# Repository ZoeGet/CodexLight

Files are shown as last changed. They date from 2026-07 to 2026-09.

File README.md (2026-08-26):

# CodexLight

[English](README.en.md) | 简体中文 | [使用说明](USAGE.md) | [English Usage Guide](USAGE.en.md)

CodexLight 是一套基于 ESP32-C3FH4 的 Codex Desktop 状态灯。Windows 端 Bridge 读取本机 Codex 会话日志，把状态转换为 `GREEN`、`RED`、`YELLOW`，再通过 USB 串口、局域网 UDP 或两者同时发送给状态灯。固件驱动三颗独立 WS2812B LED 显示空闲、工作和等待状态。

硬件采用一体化主板设计，集成 ESP32-C3FH4、2.4 GHz 天线、40 MHz 晶振、Type-C 原生 USB、电池充电与 5 V 升压以及 3.3 V 稳压电路，不需要额外安装 ESP32-C3 开发板。

本项目是社区开源项目，与 OpenAI 没有官方关联或背书。

## 当前可用方案

- 配网使用 USB 串口，不再使用 ESP32 AP 热点页面。
- 托盘程序提供 `Configure WiFi`，通过 USB 把 SSID 和密码发送给设备。
- Wi-Fi 只在连接成功后写入 ESP32 NVS；错误密码不会覆盖旧配置。
- 已保存的 Wi-Fi 会在开机后非阻塞连接，并在断线后持续重试。
- ESP32-C3 使用 SDK 默认的 Wi-Fi 发射功率，由 PHY 和地区配置决定。
- 无电脑供电启动不依赖 USB 串口，可使用板载电池接口或稳定 5 V 电源进行纯无线摆放。
- 支持 `AUTO`、`WIRED`、`WIRELESS` 三种持久化通信模式。
- 普通用户直接双击单文件 `Bridge/CodexLightTray.exe`；程序内置 Python 运行时并默认以无线模式驻留系统托盘。

## 状态定义

| 状态 | Codex 条件 | LED | GPIO |
| --- | --- | --- | --- |
| `GREEN` | 空闲、任务完成或任务中止 | 绿灯 | GPIO6 |
| `RED` | 正在思考、回复、运行工具或处理任务 | 红灯 | GPIO7 |
| `YELLOW` | 等待审批、权限确认或用户输入 | 黄灯 | GPIO5 |
| 未收到电脑心跳 | 6 秒内没有有效 USB/UDP 心跳 | 黄灯慢闪 | GPIO5 |

Bridge 兼容 Codex 会话日志中的普通工具调用和自定义工具调用事件，因此系统权限审批、沙箱授权和显式用户输入等待都能进入黄色状态。

首次收到有效电脑心跳时，绿灯会闪烁 2 秒作为连接提示，然后显示真实状态。任务完成后的绿色会保持到下一次任务开始、进入等待状态或连接断开。

## 快速开始

1. 编译并烧录固件：

   ```powershell
   cd Firmware
   pio run
   pio run -t upload --upload-port COM4
   ```

2. 双击启动托盘 EXE，默认进入无线模式，无需另行安装 Python：

   ```text
   Bridge\CodexLightTray.exe
   ```

3. 第一次使用时，用可传输数据的 Type-C 线连接设备，右键托盘图标选择 `Configure WiFi`，输入路由器 SSID 和密码。
4. Wi-Fi 保存成功后，可以拔掉电脑 USB，改用稳定 5 V 电源或从 MX1.25 接口接入的受保护单节锂电池供电；托盘会通过 UDP 控灯。

首次运行 EXE 会把内置运行环境和日志释放到 `%LOCALAPPDATA%\CodexLight`。Windows 防火墙首次询问时，请允许专用网络访问。

完整流程见 [USAGE.md](USAGE.md)。

## 纯无线使用

1. 先用 USB 完成一次 `Configure WiFi`。
2. 确认托盘模式是 `Wireless only`，或直接启动默认无线模式的 `CodexLightTray.exe`。
3. 断开电脑 USB，使用稳定 5 V 电源或从 MX1.25 接口接入的受保护单节锂电池给整机供电。
4. 打开托盘后，日志应出现：

   ```text
   SERIAL no matching serial port
   SERIAL setup skipped; using saved firmware mode.
   UDP ack from 192.168.x.x CODEXLIGHT/1 ACK ... active=WIRELESS state=...
   ```

这表示设备未接电脑串口，但已通过 Wi-Fi UDP 正常工作。

## 无串口诊断灯码

| 灯码 | 含义 |
| --- | --- |
| 红黄交替 | 没有读到 Wi-Fi 配置，需要 USB 配网 |
| 红色双闪循环 | 有 Wi-Fi 配置，但正在重连或连接失败 |
| 黄灯慢闪 | Wi-Fi 已连接，正在等待电脑托盘 UDP 心跳 |
| 正常红/绿/黄 | 已收到电脑状态，系统正常工作 |

## 硬件

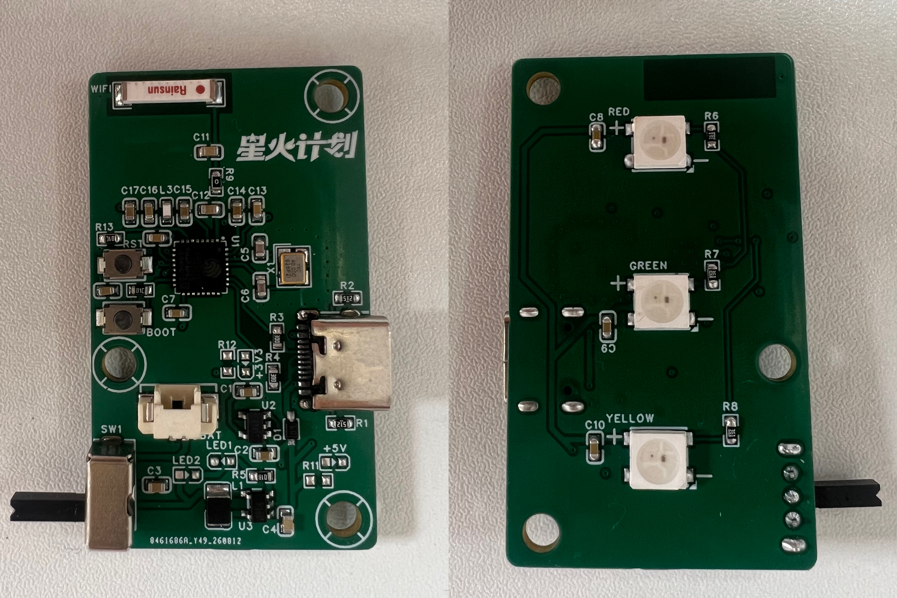
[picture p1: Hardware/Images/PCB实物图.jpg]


上图为当前一体化主板的正反面焊接实物，可见 ESP32-C3FH4、Type-C、电池接口与开关、天线、ETA6093S2F 电源区域以及三颗独立 WS2812B 状态灯。

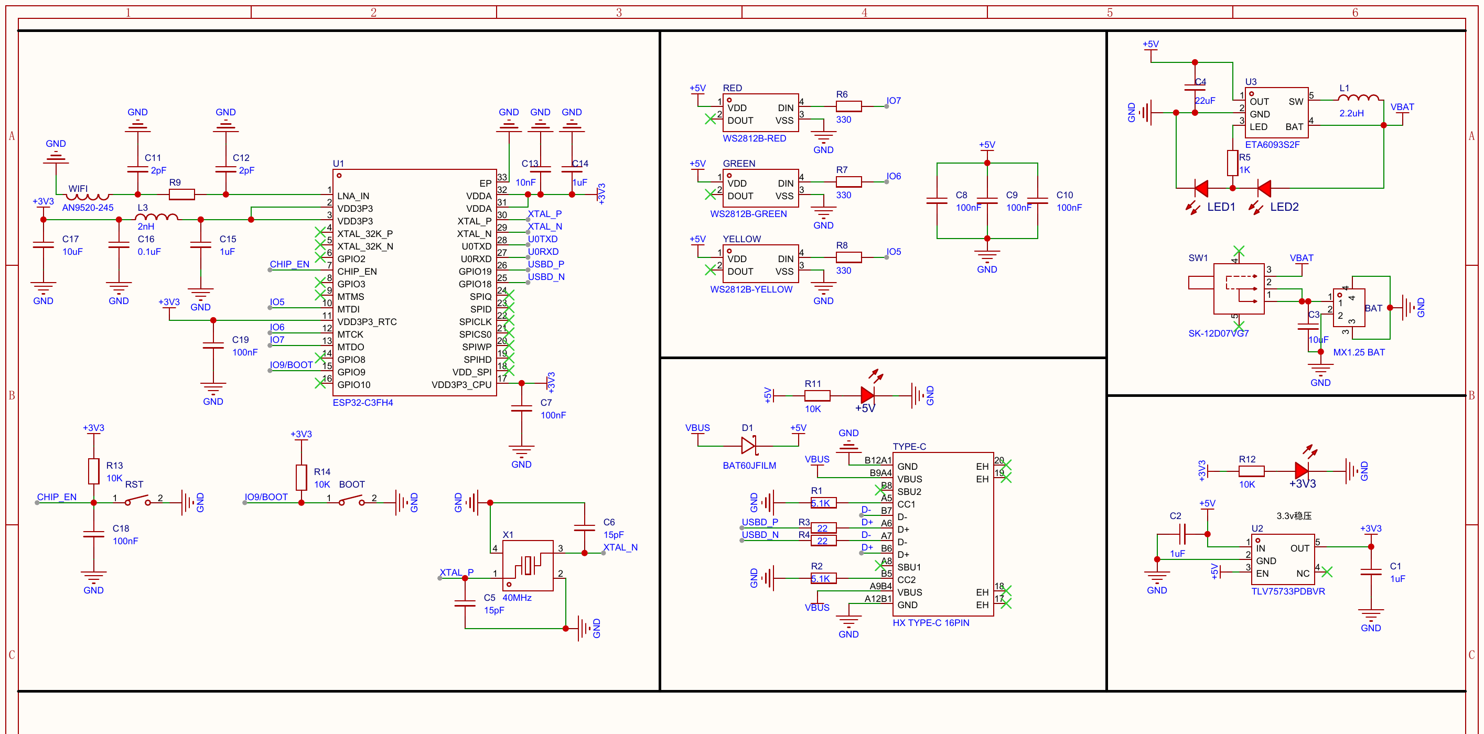
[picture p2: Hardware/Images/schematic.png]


当前硬件是围绕 ESP32-C3FH4 设计的一体化主板，完整原理图见 [Hardware/Schematic/Schematic.pdf](Hardware/Schematic/Schematic.pdf)。

| 功能模块 | 主要器件与连接 |
| --- | --- |
| 主控与时钟 | ESP32-C3FH4，外接 40 MHz 晶振；RST 接 CHIP_EN，BOOT 接 GPIO9 |
| 无线射频 | AN9520-245 2.4 GHz 天线，R9/C11/C12 预留射频匹配网络 |
| USB Type-C | 原生 USB D+/D- 分别连接 GPIO19/GPIO18，并串联 22 Ω；CC1、CC2 各使用 5.1 kΩ 下拉 |
| USB 供电 | VBUS 经 BAT60JFILM 肖特基二极管接入系统 +5 V |
| 电池供电 | ETA6093S2F 负责单节锂电池开关充电和 5 V 同步升压，使用 2.2 µH 电感、22 µF 输出电容、MX1.25 电池接口和电源开关 |
| 3.3 V 电源 | TLV75733PDBVR 将 +5 V 稳压为 +3.3 V，为 ESP32-C3FH4 和逻辑电路供电 |
| 状态灯 | 黄灯 GPIO5、绿灯 GPIO6、红灯 GPIO7；每路串联 330 Ω，并配置 100 nF 去耦电容 |

<p>
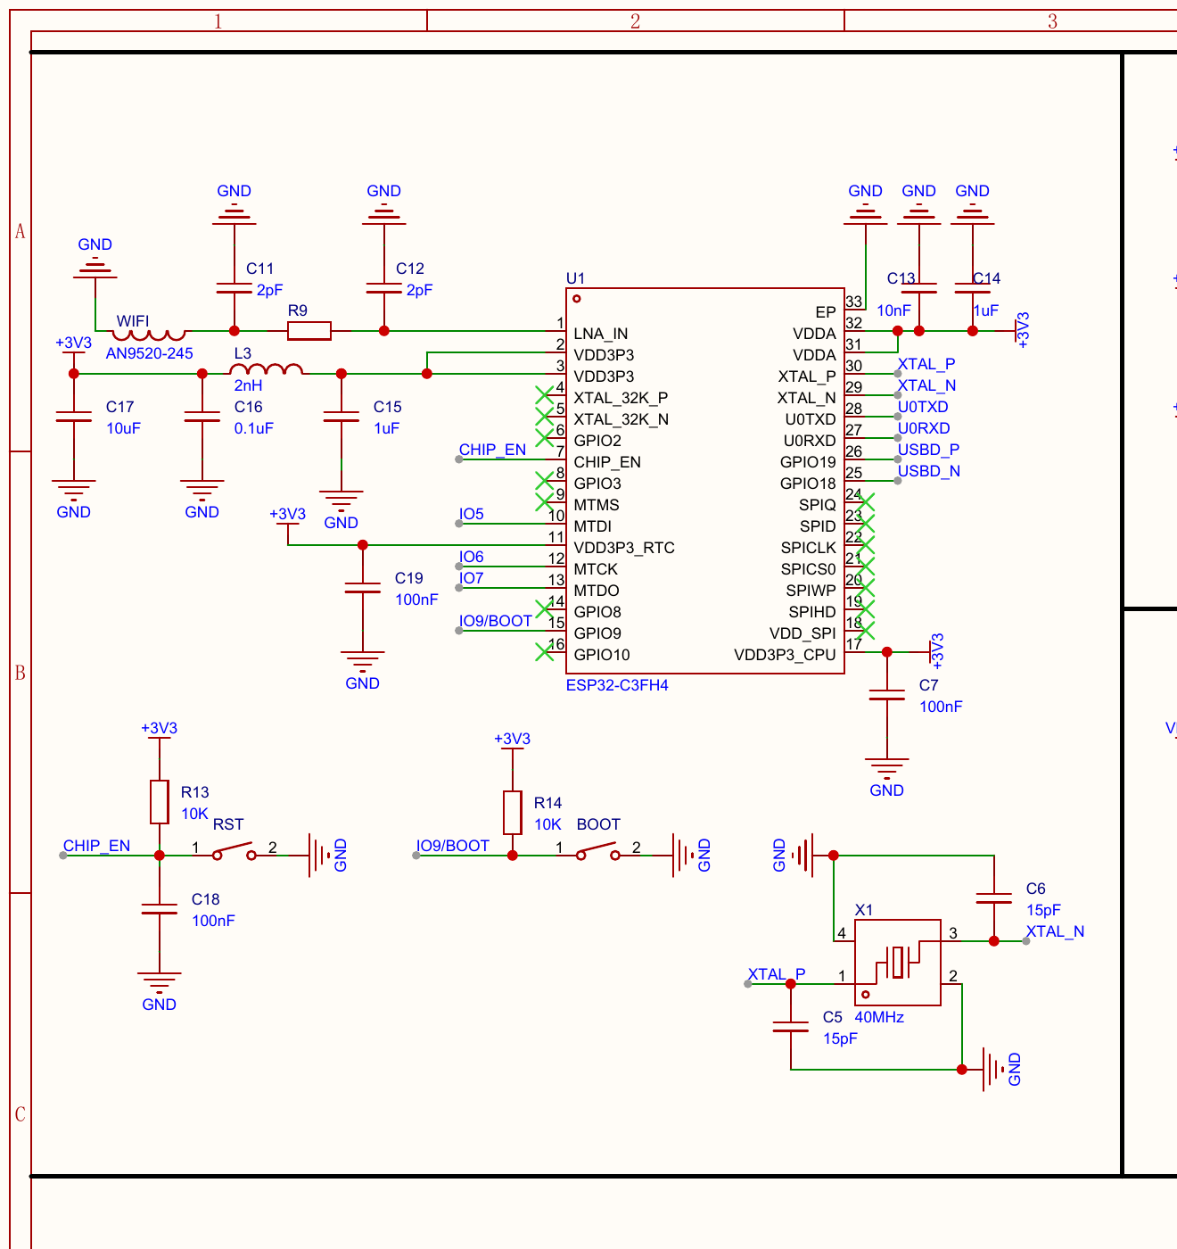
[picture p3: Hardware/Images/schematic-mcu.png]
  
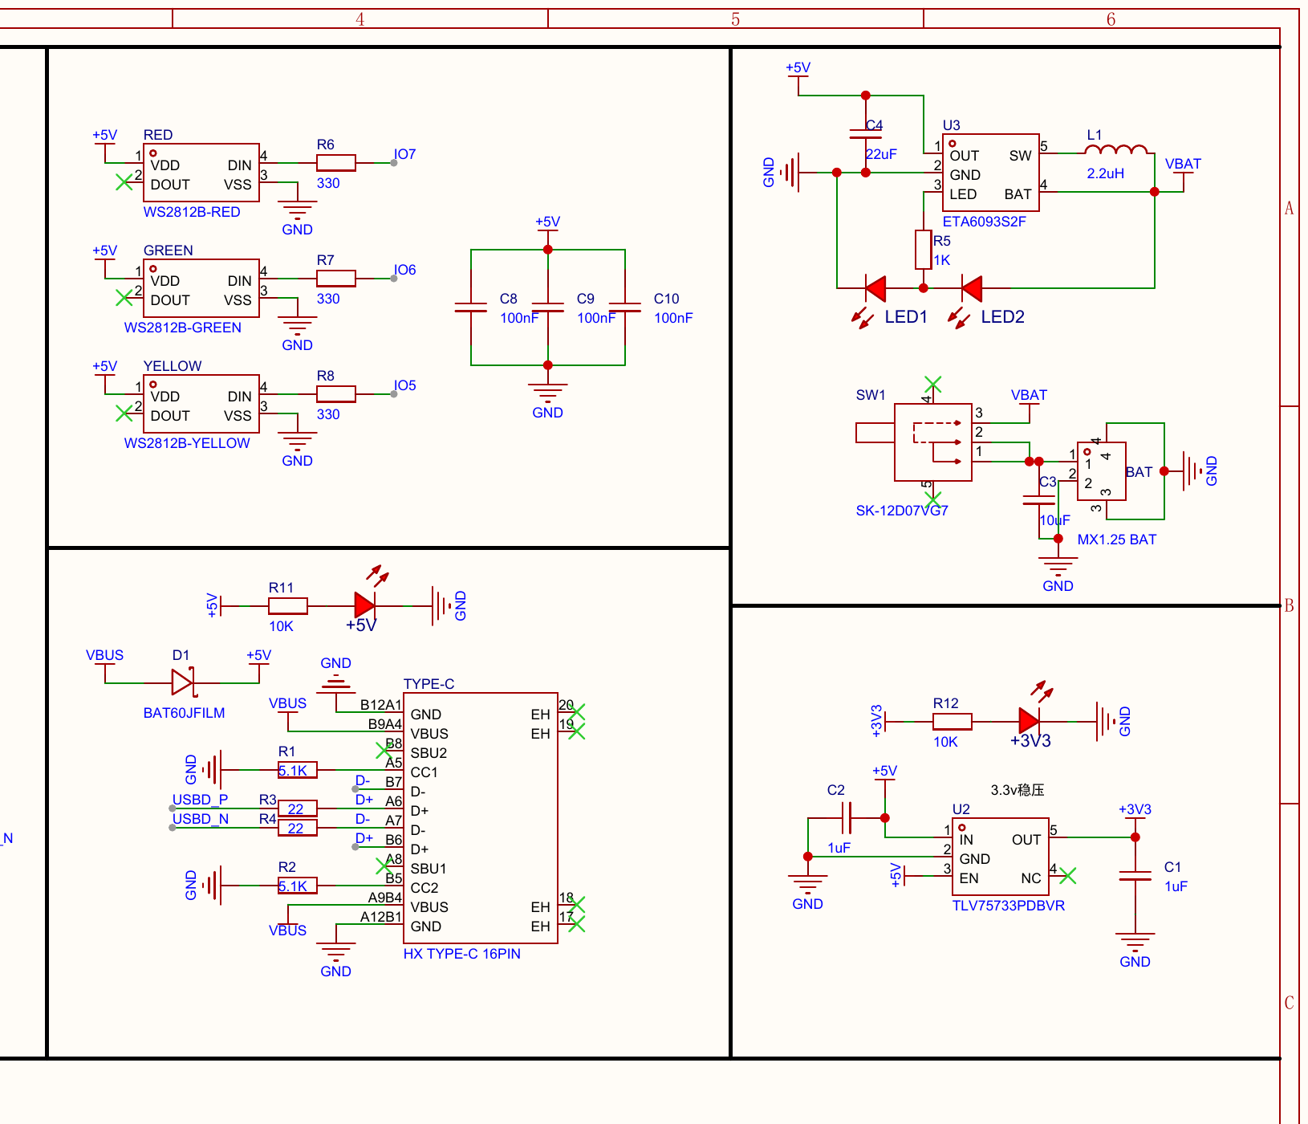
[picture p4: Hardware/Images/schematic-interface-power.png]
  
</p>

左图为 ESP32-C3FH4 主控、射频、晶振及 RST/BOOT 电路，右图为三路状态灯、Type-C、电池管理和 3.3 V 稳压电路。

三颗 WS2812B 使用三路独立数据输入，不是串联灯带。灯珠使用 +5 V 供电，ESP32-C3FH4 使用 +3.3 V 供电，二者必须共地。当前固件使用 `NEO_GRB + NEO_KHZ800`，默认亮度为 `DEFAULT_BRIGHTNESS = 50`，可在 [Firmware/include/config.h](Firmware/include/config.h) 中配置。

ETA6093S2F 的 `LED` 引脚通过 R5（1 kΩ）连接 LED1、LED2，用于显示充电和升压工作状态；L1（2.2 µH）连接 `SW` 与 `VBAT`，C4（22 µF）用于 +5 V 输出滤波，C3（10 µF）用于电池侧去耦。电池必须核对接口极性并带有保护电路。更详细的电路说明和组装注意事项见 [开源平台项目说明](Docs/立创开源平台项目说明.md)。

## 目录结构

```text
CodexLight/
├── Bridge/        # Windows 日志监听、串口/UDP 发送和托盘程序
├── Firmware/      # ESP32-C3 PlatformIO 固件
├── Hardware/      # BOM、原理图、PCB、Gerber、贴片坐标、外壳 STL
├── Docs/          # 使用与实现说明
├── README.md      # 中文项目说明
├── README.en.md   # English project documentation
├── USAGE.md       # 中文使用手册
└── USAGE.en.md    # English usage guide
```

## 验证

```powershell
python -B -m py_compile Bridge\Source\codex_light_monitor.py
powershell -NoProfile -Command "$e=$null; [System.Management.Automation.PSParser]::Tokenize((Get-Content -LiteralPath 'Bridge\Source\CodexLightTray.ps1' -Raw), [ref]$e) | Out-Null; if($e){$e; exit 1}else{'OK'}"
cd Firmware
pio run
```

## 许可

本项目使用 [MIT License](LICENSE)。第三方依赖遵循各自许可。

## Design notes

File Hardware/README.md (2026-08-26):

# CodexLight Hardware

[项目主页](../README.md) | [Project Home](../README.en.md)

本目录包含 CodexLight 的 BOM、原理图、PCB 源工程、Gerber、贴片坐标文件和 3D 打印外壳。

This directory contains the CodexLight bill of materials, schematic, PCB source project, Gerber files, component placement list, and 3D-printable enclosure.

## Files / 文件

| Path | Description |
| --- | --- |
| `BOM/BOM.xls` | 物料清单 / Bill of materials |
| `Schematic/Schematic.pdf` | 原理图 PDF / Schematic PDF |
| `PCB/Source/CodexLight.epro2` | PCB 源工程 / PCB source project |
| `PCB/Gerber/CodexLight_PCB_Gerber.zip` | Gerber 制造包 / Gerber fabrication package |
| `PCB/Assembly/CodexLight_PCB_CPL.csv` | 元件贴片坐标文件 / Component placement list |
| `Enclosure/CodexLight_T.stl` | 上壳 / Top enclosure |
| `Enclosure/CodexLight_B.stl` | 下壳 / Bottom enclosure |

## LED Connections / LED 连接

| LED | GPIO |
| --- | --- |
| Yellow WS2812B DIN / 黄灯 DIN | GPIO5 |
| Green WS2812B DIN / 绿灯 DIN | GPIO6 |
| Red WS2812B DIN / 红灯 DIN | GPIO7 |

三颗 LED 使用独立数据线，不是串联灯带。LED 电源和 ESP32-C3 必须共地，并使用稳定 5 V 供电。

The three LEDs use independent data lines, not a chained strip. The LED supply and ESP32-C3 must share ground, and a stable 5 V supply is required.

## Assembly Photo / 焊接实物



图片展示当前一体化主板正反面的焊接结果，包括主控、射频、USB、电池管理、稳压和三颗状态灯区域。

The image shows the assembled front and back sides of the current all-in-one board, including the MCU, RF, USB, battery-management, regulator, and status-LED sections.

## Standalone Power / 独立供电

纯无线使用时，可以通过 Type-C/稳定 5 V 电源供电，也可以从 MX1.25 接口接入带保护的单节锂电池。ETA6093S2F 负责单节锂电池开关充电和 5 V 同步升压，TLV75733PDBVR 再生成 ESP32-C3FH4 使用的 3.3 V。接入电池前必须核对接口极性。

For wireless-only use, power the device through USB Type-C or a stable 5 V supply, or connect a protected single-cell Li-ion battery through MX1.25. The ETA6093S2F handles switch-mode charging and synchronous 5 V boost power, while the TLV75733PDBVR generates 3.3 V for the ESP32-C3FH4. Verify battery connector polarity before connection.

## Notes / 注意

- 固件默认使用 `NEO_GRB + NEO_KHZ800`。
- 如果更换不同批次 WS2812B 后颜色不对，请检查色序、DIN 方向、焊接和供电。
- 固件烧录和首次 Wi-Fi 配网需要可传输数据的 Type-C 线。
- ETA6093S2F 的 `LED` 引脚通过 R5（1 kΩ）驱动 LED1、LED2；L1 为 2.2 µH，+5 V 输出端 C4 为 22 µF，电池侧 C3 为 10 µF。电池应带保护电路并核对接口极性。
- 当前 `BOM.xls` 和 `CodexLight_PCB_CPL.csv` 仍包含旧的 ETA9697E8A 记录，正式生产前需要从新版 EasyEDA 工程重新导出并核对封装、坐标和旋转方向。
- `CodexLight_PCB_CPL.csv` 包含顶层和底层元件坐标；提交贴片订单前应在生产平台预览并核对元件层、坐标和旋转方向。

- Firmware defaults to `NEO_GRB + NEO_KHZ800`.
- If another WS2812B batch displays incorrect colors, verify pixel order, DIN orientation, soldering, and power.
- Firmware upload and first-time Wi-Fi provisioning require a data-capable USB Type-C cable.
- The ETA6093S2F `LED` pin drives LED1 and LED2 through R5 (1 kΩ). L1 is 2.2 µH, C4 is 22 µF on the +5 V output, and C3 is 10 µF on the battery side. Use a protected battery and verify connector polarity.
- The current `BOM.xls` and `CodexLight_PCB_CPL.csv` still contain the previous ETA9697E8A entry. Re-export them from the updated EasyEDA project and verify the footprint, coordinates, and rotation before production.
- `CodexLight_PCB_CPL.csv` contains top- and bottom-side component coordinates. Preview the assembly order and verify layer, position, and rotation data before production.

## License

Unless a third-party component states otherwise, hardware files follow the repository [MIT License](../LICENSE).

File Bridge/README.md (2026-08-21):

# CodexLight Bridge

[English](README_en.md) | 简体中文 | [项目主页](../README.md)

Bridge 运行在 Windows 电脑上，读取本机 Codex Desktop 会话日志，把状态映射为 `GREEN`、`RED`、`YELLOW`，再通过 USB 串口、局域网 UDP 或两者同时发送给 ESP32-C3。

## 功能

- 监听 `~/.codex/sessions/**/*.jsonl` 和 `~/.codex/logs_2.sqlite`。
- 支持 USB 串口、UDP、AUTO 混合模式。
- 提供 Windows 托盘菜单：配网、切换模式、查看日志、重启监控、退出。
- 通过 USB 串口为设备配置 Wi-Fi，不使用 ESP32 AP 热点。
- 自动记住最近发现的 UDP 设备，方便下次启动继续使用无线连接。
- 无电脑 USB 时，托盘会跳过串口设置并继续用已保存的无线模式发送 UDP。

## 状态规则

| Codex 事件 | 输出 |
| --- | --- |
| `task_started`、推理、消息、工具调用和工具输出 | `RED` |
| 工具调用需要审批、权限或用户输入 | `YELLOW` |
| `task_complete` 或 `turn_aborted` | `GREEN` |

Bridge 同时兼容 `function_call` / `function_call_output` 和 `custom_tool_call` / `custom_tool_call_output`。当工具调用包含 `require_escalated`、`sandbox_permissions`、`request_user_input` 或其他审批/权限标记时，状态保持为 `YELLOW`，直到对应的工具输出到达。

Bridge 只发送颜色状态，不发送 Codex 消息正文、工具输出、API Key 或登录令牌。

## 依赖

直接使用已构建的 `CodexLightTray.exe` 不需要另行安装 Python。只有从源码启动或重新构建 EXE 时需要本机 Python；源码启动还需要：

```powershell
python -m pip install pyserial
```

## 托盘启动

普通用户直接双击单文件程序：

```text
Bridge\CodexLightTray.exe
```

EXE 内置 64 位 Python 运行时和串口库，首次启动会释放到 `%LOCALAPPDATA%\CodexLight`，日志和本地设备配置也保存在该目录。首次使用 UDP 时，Windows 防火墙可能询问是否允许网络访问，请允许专用网络。

从源码启动时，推荐双击隐藏启动器，默认进入 `WIRELESS` 模式：

```text
Bridge\Source\start_codex_light_tray.vbs
```

旧批处理也可用，但可能短暂显示控制台窗口：

```text
Bridge\Source\start_codex_light_tray.bat
```

托盘菜单：

- `Configure WiFi`：通过 USB 写入路由器 SSID/密码。
- `Connection mode`：切换 `Auto (wired + wireless)`、`Wired only`、`Wireless only`。
- `Open log folder`：打开当前运行版本的日志目录；EXE 版为 `%LOCALAPPDATA%\CodexLight\logs`，源码版为 `Bridge\Source\logs`。
- `Restart monitor`：重启监控进程。
- `Exit`：退出。

重新构建单文件 EXE：

```powershell
powershell -ExecutionPolicy Bypass -File Bridge\Source\build_tray_exe.ps1
```

输出文件为 `Bridge\CodexLightTray.exe`。构建过程使用本机 64 位 Python 和 Windows 自带的 .NET Framework C# 编译器，不需要联网。

## Wi-Fi 配网

托盘 `Configure WiFi` 会暂停监控进程，打开串口，发送：

```text
WIFI_SET <ssid><TAB><password>
```

设备连接成功后返回：

```text
WIFI_SET_OK <ssid> <ip>
```

EXE 版失败日志保存到：

```text
%LOCALAPPDATA%\CodexLight\logs\wifi_setup.out.log
%LOCALAPPDATA%\CodexLight\logs\wifi_setup.err.log
```

源码版失败日志保存到 `Bridge\Source\logs`。

命令行配网：

```powershell
python Bridge\Source\codex_light_monitor.py --serial auto --wifi-ssid "YourWifi" --wifi-password "YourPassword"
```

## 运行模式

| 模式 | Bridge 行为 |
| --- | --- |
| `WIRED` | 打开串口并只通过 USB 发送状态 |
| `WIRELESS` | 通过 UDP 发送状态；如果 USB 存在，会用串口保存 `MODE WIRELESS` 后释放；如果 USB 不存在，会直接使用设备已保存模式 |
| `AUTO` | 串口和 UDP 同时启用，固件优先使用新鲜串口心跳 |

手动运行：

```powershell
python Bridge\Source\codex_light_monitor.py --serial auto --baud 115200
python Bridge\Source\codex_light_monitor.py --udp --udp-port 4210
python Bridge\Source\codex_light_monitor.py --serial auto --baud 115200 --udp --udp-port 4210 --firmware-mode AUTO
```

## 常用参数

| 参数 | 说明 |
| --- | --- |
| `--serial COM4` | 指定串口 |
| `--serial auto` | 自动选择常见 ESP32/USB 串口 |
| `--baud 115200` | 串口波特率 |
| `--udp` | 启用 UDP 状态发送和发现 |
| `--udp-port 4210` | UDP 端口 |
| `--firmware-mode AUTO` | 通过串口保存固件模式 |
| `--serial-setup-only` | 串口只用于模式设置，确认后释放 |
| `--reset-on-connect` | 打开串口后发送 ESP32 reset pulse，用于无线托盘启动时初始化设备 |
| `--wifi-ssid` / `--wifi-password` | 一次性 USB Wi-Fi 配网 |
| `--wifi-config path.json` | 从 JSON 文件读取 `{ "ssid": "...", "password": "..." }` |

## 日志

- EXE 版：`%LOCALAPPDATA%\CodexLight\logs`
- 源码版：`Bridge\Source\logs`
- 两种版本均包含 `codex_light_monitor.out.log`、`codex_light_monitor.err.log`、`wifi_setup.out.log`、`wifi_setup.err.log`。

## 验证

```powershell
python -B -m py_compile Bridge\Source\codex_light_monitor.py
powershell -NoProfile -Command "$e=$null; [System.Management.Automation.PSParser]::Tokenize((Get-Content -LiteralPath 'Bridge\Source\CodexLightTray.ps1' -Raw), [ref]$e) | Out-Null; if($e){$e; exit 1}else{'OK'}"
```

## License

Bridge 遵循仓库根目录的 [MIT License](../LICENSE)。

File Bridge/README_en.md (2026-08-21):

# CodexLight Bridge

English | [简体中文](README.md) | [Project Home](../README.en.md)

The Bridge runs on the Windows computer hosting Codex Desktop. It reads local Codex session logs, maps activity to `GREEN`, `RED`, or `YELLOW`, and sends the state to the ESP32-C3 over USB serial, LAN UDP, or both.

## Features

- Monitors `~/.codex/sessions/**/*.jsonl` and `~/.codex/logs_2.sqlite`.
- Supports USB serial, UDP, and mixed AUTO mode.
- Provides a Windows tray menu for Wi-Fi setup, mode switching, logs, monitor restart, and exit.
- Configures device Wi-Fi over USB serial. The firmware no longer uses an ESP32 AP portal.
- Remembers the most recently discovered UDP device for wireless startup.
- When no computer USB is connected, the tray skips serial setup and continues UDP using the device's saved wireless mode.

## State Rules

| Codex event | Output |
| --- | --- |
| `task_started`, reasoning, messages, tool calls, and tool outputs | `RED` |
| A tool call requires approval, permission, or user input | `YELLOW` |
| `task_complete` or `turn_aborted` | `GREEN` |

The Bridge supports both `function_call` / `function_call_output` and `custom_tool_call` / `custom_tool_call_output`. When a tool call contains `require_escalated`, `sandbox_permissions`, `request_user_input`, or another approval/permission marker, the state remains `YELLOW` until the matching tool output arrives.

The Bridge sends only color states. It never sends Codex message text, tool output, API keys, or login tokens to the device.

## Dependency

The built `CodexLightTray.exe` does not require a separate Python installation. Local Python is needed only when running from source or rebuilding the EXE; source mode also requires:

```powershell
python -m pip install pyserial
```

## Tray Startup

For normal use, double-click the standalone executable:

```text
Bridge\CodexLightTray.exe
```

The EXE embeds a 64-bit Python runtime and pyserial. On first launch it extracts runtime files to `%LOCALAPPDATA%\CodexLight`; logs and local device configuration are stored there as well. Windows Firewall may ask for network access the first time UDP is used; allow private networks.

When running from source, use the hidden launcher. It defaults to `WIRELESS` mode:

```text
Bridge\Source\start_codex_light_tray.vbs
```

The legacy batch launcher is also available, but it may briefly show a console window:

```text
Bridge\Source\start_codex_light_tray.bat
```

Tray menu:

- `Configure WiFi`: write router SSID/password over USB.
- `Connection mode`: switch between `Auto (wired + wireless)`, `Wired only`, and `Wireless only`.
- `Open log folder`: open the active runtime log directory; `%LOCALAPPDATA%\CodexLight\logs` for the EXE and `Bridge\Source\logs` for source mode.
- `Restart monitor`: restart the monitor process.
- `Exit`: quit.

Rebuild the standalone EXE with:

```powershell
powershell -ExecutionPolicy Bypass -File Bridge\Source\build_tray_exe.ps1
```

The output is `Bridge\CodexLightTray.exe`. The build uses local 64-bit Python and the Windows .NET Framework C# compiler, and does not require network access.

## Wi-Fi Provisioning

The tray `Configure WiFi` action pauses the monitor process, opens serial, and sends:

```text
WIFI_SET <ssid><TAB><password>
```

On success, the device replies:

```text
WIFI_SET_OK <ssid> <ip>
```

EXE failure logs are written to:

```text
%LOCALAPPDATA%\CodexLight\logs\wifi_setup.out.log
%LOCALAPPDATA%\CodexLight\logs\wifi_setup.err.log
```

Source-mode failure logs are written under `Bridge\Source\logs`.

Command-line provisioning:

```powershell
python Bridge\Source\codex_light_monitor.py --serial auto --wifi-ssid "YourWifi" --wifi-password "YourPassword"
```

## Run Modes

| Mode | Bridge behavior |
| --- | --- |
| `WIRED` | Opens serial and sends states only over USB |
| `WIRELESS` | Sends states over UDP; if USB exists, serial saves `MODE WIRELESS` and is released; if USB is absent, the saved firmware mode is used |
| `AUTO` | Enables serial and UDP; firmware prefers a fresh serial heartbeat |

Manual commands:

```powershell
python Bridge\Source\codex_light_monitor.py --serial auto --baud 115200
python Bridge\Source\codex_light_monitor.py --udp --udp-port 4210
python Bridge\Source\codex_light_monitor.py --serial auto --baud 115200 --udp --udp-port 4210 --firmware-mode AUTO
```

## Common Options

| Option | Description |
| --- | --- |
| `--serial COM4` | Use a specific serial port |
| `--serial auto` | Auto-select a common ESP32/USB serial device |
| `--baud 115200` | Serial baud rate |
| `--udp` | Enable UDP state output and discovery |
| `--udp-port 4210` | UDP port |
| `--firmware-mode AUTO` | Persist firmware mode over serial |
| `--serial-setup-only` | Use serial only for mode setup, then release it |
| `--reset-on-connect` | Pulse ESP32 reset lines after opening serial; used by wireless tray startup to initialize the device |
| `--wifi-ssid` / `--wifi-password` | One-shot USB Wi-Fi provisioning |
| `--wifi-config path.json` | Read `{ "ssid": "...", "password": "..." }` from JSON |

## Logs

- EXE build: `%LOCALAPPDATA%\CodexLight\logs`
- Source mode: `Bridge\Source\logs`
- Both contain `codex_light_monitor.out.log`, `codex_light_monitor.err.log`, `wifi_setup.out.log`, and `wifi_setup.err.log`.

## Verification

```powershell
python -B -m py_compile Bridge\Source\codex_light_monitor.py
powershell -NoProfile -Command "$e=$null; [System.Management.Automation.PSParser]::Tokenize((Get-Content -LiteralPath 'Bridge\Source\CodexLightTray.ps1' -Raw), [ref]$e) | Out-Null; if($e){$e; exit 1}else{'OK'}"
```

## License

The Bridge is covered by the repository's [MIT License](../LICENSE).

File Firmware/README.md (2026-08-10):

# CodexLight Firmware

[项目主页](../README.md) | [Project Home](../README.en.md)

本目录是 ESP32-C3 端 PlatformIO Arduino 固件。固件负责 USB Wi-Fi 配网、STA 联网、USB 串口/UDP 心跳接收、通信模式持久化、无串口启动诊断灯码和三路 WS2812B 状态显示。

This directory contains the ESP32-C3 PlatformIO Arduino firmware. It handles USB Wi-Fi provisioning, STA networking, USB serial/UDP heartbeats, persistent transport modes, standalone LED diagnostics, and three independent WS2812B status LEDs.

## Build Environment / 构建环境

```ini
platform = espressif32@6.6.0
board = esp32-c3-devkitm-1
framework = arduino
monitor_speed = 115200
```

PlatformIO installs the external dependency automatically:

- `Adafruit NeoPixel`

当前固件不再依赖 `WiFiManager`、`ESPAsyncWebServer` 或 AP 配网页面。

The current firmware no longer depends on `WiFiManager`, `ESPAsyncWebServer`, or an AP provisioning portal.

## Build and Upload / 编译与烧录

```powershell
cd Firmware
pio run
pio run -t upload --upload-port COM4
pio device monitor --port COM4 --baud 115200
```

普通串口监视器会占用 COM 口。使用 Bridge 或托盘前请关闭 PlatformIO Monitor。

Close PlatformIO Monitor before starting the Bridge or tray because only one process can use the COM port.

## Main Configuration / 主要配置

Edit `include/config.h`:

| Setting | Default | Description |
| --- | --- | --- |
| `YELLOW_LED_PIN` | `5` | Yellow LED data pin |
| `GREEN_LED_PIN` | `6` | Green LED data pin |
| `RED_LED_PIN` | `7` | Red LED data pin |
| `DEFAULT_BRIGHTNESS` | `50` | NeoPixel brightness |
| `SERIAL_BAUD` | `115200` | USB CDC baud rate |
| `UDP_PORT` | `4210` | UDP listen/discovery port |
| `LINK_TIMEOUT_MS` | `6000` | Desktop heartbeat timeout |
| `WIFI_CONNECT_TIMEOUT_MS` | `15000` | Blocking connect timeout used only during USB provisioning validation |
| `WIFI_RECONNECT_INTERVAL_MS` | `10000` | Non-blocking saved Wi-Fi retry interval |
| `DEFAULT_TRANSPORT_MODE` | `AUTO` | Default mode when NVS has none |
| `DEBUG_SERIAL` | `false` | Default debug logging; keep disabled for standalone wireless operation |

`CONFIG_AP_*` constants are retained only for compatibility. The main firmware does not start a SoftAP.

`CONFIG_AP_*` 常量仅保留兼容用途，主固件不会启动热点。

## Wi-Fi Provisioning / Wi-Fi 配网

Use USB serial:

```text
WIFI_SET <ssid><TAB><password>
```

During provisioning, the firmware validates the credentials by attempting STA connection. Credentials are saved in Preferences namespace `wifi` only after successful connection:

```text
ssid
password
```

配网失败不会覆盖旧配置。保存过 Wi-Fi 后，启动时使用非阻塞连接；如果连接失败，固件保留凭据并按 `WIFI_RECONNECT_INTERVAL_MS` 持续重试。

Failed provisioning does not overwrite existing credentials. Once Wi-Fi is saved, boot uses a non-blocking connect path. If the connection fails, credentials are kept and the firmware retries every `WIFI_RECONNECT_INTERVAL_MS`.

Clear Wi-Fi:

```text
CLEAR_WIFI
```

## Transport Modes / 通信模式

| Mode | Behavior |
| --- | --- |
| `WIRED` | Accept USB serial heartbeat only |
| `WIRELESS` | Accept UDP heartbeat only |
| `AUTO` | Accept both; fresh USB heartbeat has priority |

Commands:

```text
MODE WIRED
MODE WIRELESS
MODE AUTO
STATUS
```

The selected mode is saved in Preferences namespace `codexlight`, key `transport`.

## LED Runtime and Diagnostics / LED 运行与诊断

| Pattern | Meaning |
| --- | --- |
| Solid green | Idle, task complete, or task aborted |
| Solid red | Codex is working |
| Solid yellow | Waiting for approval, permission, or user input |
| Green blink for 2 seconds | First desktop heartbeat connected |
| Slow yellow blink | Wi-Fi is connected but no desktop heartbeat has arrived |
| Alternating red/yellow | No saved Wi-Fi credentials |
| Repeating red double-blink | Saved Wi-Fi exists but reconnect is in progress or failed |

独立供电时不要依赖串口输出判断状态，直接看灯码即可。

When running from a power bank or battery, use the LED diagnostics instead of serial output.

## Serial Commands / 串口命令

```text
GREEN
RED
YELLOW
PING
STATUS
MODE WIRED
MODE WIRELESS
MODE AUTO
WIFI_CONFIG
WIFI_SET <ssid><TAB><password>
CLEAR_WIFI
LED_TEST RED
LED_TEST GREEN
LED_TEST YELLOW
LED_TEST OFF
```

`WIFI_CONFIG` only prints the USB provisioning hint. It does not open an AP.

`WIFI_CONFIG` 只提示使用 USB 配网，不会打开热点。

## UDP Protocol / UDP 协议

Accepted packets:

```text
CODEXLIGHT/1 GREEN
CODEXLIGHT/1 RED
CODEXLIGHT/1 YELLOW
CODEXLIGHT/1 PING
```

Acknowledgement:

```text
CODEXLIGHT/1 ACK mac=<MAC> mode=<MODE> active=<TRANSPORT> state=<STATE>
```

Discovery:

```text
CODEXLIGHT/1 HELLO mac=<MAC> mode=<MODE>
```

## Files / 文件

- `src/main.cpp`: serial commands, UDP heartbeat, transport selection, LED state machine, diagnostics.
- `src/config_portal.cpp`: STA Wi-Fi, USB provisioning wrapper, non-blocking saved Wi-Fi reconnect.
- `src/storage.cpp`: Preferences read/write for Wi-Fi credentials.
- `src/led.cpp`: three independent Adafruit NeoPixel outputs.
- `include/config.h`: user-editable GPIO, timing, brightness, port, and Wi-Fi power settings.
- `platformio.ini`: PlatformIO environment and dependencies.

## NVS and Reset / NVS 与擦除

Wi-Fi credentials and transport mode are stored in NVS. Normal firmware upload does not erase them.

```powershell
pio run -t erase --upload-port COM4
pio run -t upload --upload-port COM4
```

Usually `CLEAR_WIFI` and `MODE ...` are enough. Full erase is only needed for factory reset or corrupted NVS.

## License

Firmware follows the repository [MIT License](../LICENSE). Third-party dependencies keep their own licenses.

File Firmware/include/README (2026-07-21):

# Firmware Headers

Project header files / 项目头文件：

- `config.h`: GPIO assignments, brightness, serial baud, UDP port, timeouts, default transport mode, and LED colors. AP constants are retained for compatibility but the main firmware does not start an AP.
- `config_portal.h`: STA Wi-Fi connection and USB provisioning wrapper. The name is kept for compatibility with older code.
- `storage.h`: Preferences storage for Wi-Fi SSID/password.
- `led.h`: three-channel LED controller interface.

用户通常只需要修改 `config.h`。修改后重新运行 `pio run` 并烧录。

Users normally edit `config.h` only. Rebuild and upload after changing it.

See `Firmware/README.md` and the repository root README for complete instructions.

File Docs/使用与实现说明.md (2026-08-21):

# CodexLight 使用与实现说明

[English](USAGE_AND_IMPLEMENTATION.md) | 简体中文 | [返回文档索引](README.md) | [项目主页](../README.md)

本文合并项目操作手册和技术实现说明，覆盖固件烧录、USB Wi-Fi 配网、有线/无线运行、排障和维护。

## 硬件连接

| LED | 数据引脚 | 状态 |
| --- | --- | --- |
| 黄色 WS2812B | GPIO5 | 未连接、等待或诊断 |
| 绿色 WS2812B | GPIO6 | 连接动画或任务完成 |
| 红色 WS2812B | GPIO7 | Codex 正在工作或 Wi-Fi 重连诊断 |

三颗 WS2812B 分别使用独立 DIN。VCC 接稳定 5 V，GND 与 ESP32-C3 共地。

## 编译与烧录

```powershell
cd C:\path\to\CodexLight\Firmware
pio run
pio run -t upload --upload-port COM4
pio device monitor --port COM4 --baud 115200
```

启动 Bridge 前请关闭 PlatformIO Monitor，因为它们会占用同一个串口。

## USB Wi-Fi 配网

当前固件不会开启 SoftAP 配网页面。配网通过 USB 串口完成。

托盘流程：

1. USB 连接设备。
2. 双击 `Bridge\CodexLightTray.exe`，该程序无需另行安装 Python，并默认进入 `WIRELESS` 模式。
3. 右键托盘图标，选择 `Configure WiFi`。
4. 输入 SSID/密码并保存。

命令行流程：

```powershell
python Bridge\Source\codex_light_monitor.py --serial auto --wifi-ssid "YourWifi" --wifi-password "YourPassword"
```

固件命令：

```text
WIFI_SET <ssid><TAB><password>
```

只有当 `WiFi.status() == WL_CONNECTED` 时，固件才保存 Wi-Fi。失败尝试不会写入 Flash。

## 通信模式

| 模式 | 行为 |
| --- | --- |
| `WIRED` | 只接收 USB 串口心跳 |
| `WIRELESS` | 只接收 UDP 心跳 |
| `AUTO` | 同时接收 USB 和 UDP；USB 心跳新鲜时优先 |

模式命令：

```text
MODE WIRED
MODE WIRELESS
MODE AUTO
STATUS
```

模式保存在 Preferences namespace `codexlight` 的 `transport` 键中。

## Windows 托盘

普通用户直接双击单文件 EXE，默认进入 `WIRELESS` 模式：

```text
Bridge\CodexLightTray.exe
```

EXE 内置 64 位 Python 运行时和 `pyserial`，首次启动会释放到 `%LOCALAPPDATA%\CodexLight`。Windows 防火墙首次询问时应允许专用网络。源码调试仍可使用 `Bridge\Source\start_codex_light_tray.vbs`。

托盘提供：

- `Configure WiFi`：USB 配网。
- `Connection mode`：切换 AUTO、WIRED、WIRELESS。
- `Open log folder`：打开当前日志目录；EXE 版为 `%LOCALAPPDATA%\CodexLight\logs`，源码版为 `Bridge/Source/logs`。
- `Restart monitor`：重启 `codex_light_monitor.py`。
- `Exit`：退出托盘。

无线托盘路径在 USB 存在时只短暂打开串口，发送 reset pulse 和 `MODE WIRELESS` 后释放端口。没有 USB 串口时，它会记录 `SERIAL setup skipped; using saved firmware mode.`，然后继续通过 UDP 发送状态。

## 总体架构

```text
Codex Desktop logs
        |
        v
Bridge/Source/codex_light_monitor.py
        |
        +-- USB CDC serial: GREEN / RED / YELLOW / MODE / WIFI_SET
        +-- LAN UDP: CODEXLIGHT/1 <STATE> and CODEXLIGHT/1 PING
                         |
                         v
                  ESP32-C3 firmware
                         |
                         +-- Preferences: wifi ssid/password, transport mode
                         +-- non-blocking saved Wi-Fi reconnect
                         +-- GPIO5 yellow WS2812B
                         +-- GPIO6 green WS2812B
                         +-- GPIO7 red WS2812B
```

## Bridge 实现

Bridge 读取：

- `~/.codex/sessions/**/*.jsonl`
- `~/.codex/logs_2.sqlite`

它只向设备发送颜色状态。

| Codex 事件 | 输出 |
| --- | --- |
| `task_started`、消息、推理、工具调用、工具输出 | `RED` |
| 需要审批、权限或用户输入 | `YELLOW` |
| `task_complete` 或 `turn_aborted` | `GREEN` |

会话解析同时接受旧版 `function_call` / `function_call_output` 和新版 `custom_tool_call` / `custom_tool_call_output`。包含 `require_escalated`、`sandbox_permissions`、`request_user_input` 或其他审批/权限标记的调用会保持 `YELLOW`，直到匹配的输出事件解除等待状态。

托盘配网会暂停监控，运行一次性 `--wifi-config` 子进程，然后恢复监控。EXE 版日志写到 `%LOCALAPPDATA%\CodexLight\logs\wifi_setup.*.log`，源码版写到 `Bridge/Source/logs/wifi_setup.*.log`。

## 固件实现

主要文件：

- `Firmware/src/main.cpp`：串口命令解析、UDP 心跳、传输选择、LED 状态机、诊断灯码。
- `Firmware/src/config_portal.cpp`：STA Wi-Fi 连接、USB 配网封装、已保存 Wi-Fi 的非阻塞重连。
- `Firmware/src/storage.cpp`：Wi-Fi 凭据 Preferences 存储。
- `Firmware/src/led.cpp`：三路独立 NeoPixel 输出。
- `Firmware/include/config.h`：GPIO、亮度、超时、UDP 端口、默认模式和 ESP32-C3 Wi-Fi 发射功率。

Wi-Fi 说明：

- 固件只使用 USB 串口配网。
- 只有 STA 到达 `WL_CONNECTED` 后才保存凭据。
- 已保存 Wi-Fi 在启动时非阻塞连接，即使路由器不可达，LED 诊断和主循环也会继续运行。
- 已保存 Wi-Fi 失败时保留凭据，并每 10 秒重试。
- ESP32-C3 使用 SDK 默认发射功率，由 PHY 和地区配置决定。
- 默认关闭调试串口输出，便于独立供电无线运行。

启动流程：

```text
setup
  -> 初始化 LED 并显示启动黄灯
  -> 读取已保存 Wi-Fi 凭据
  -> 如果存在，非阻塞启动 STA 连接
  -> 读取已保存通信模式
loop
  -> 需要时继续尝试 Wi-Fi 重连
  -> 处理可用 USB 串口命令
  -> Wi-Fi 已连接时维护 UDP
  -> 选择活动传输
  -> 渲染 LED 状态或无串口诊断灯码
```

## 协议

串口命令：

```text
GREEN
RED
YELLOW
PING
STATUS
MODE WIRED
MODE WIRELESS
MODE AUTO
WIFI_CONFIG
WIFI_SET <ssid><TAB><password>
CLEAR_WIFI
LED_TEST RED
LED_TEST GREEN
LED_TEST YELLOW
LED_TEST OFF
```

UDP 状态、PING、ACK 和发现：

```text
CODEXLIGHT/1 GREEN
CODEXLIGHT/1 RED
CODEXLIGHT/1 YELLOW
CODEXLIGHT/1 PING
CODEXLIGHT/1 ACK mac=<MAC> mode=<MODE> active=<TRANSPORT> state=<STATE>
CODEXLIGHT/1 HELLO mac=<MAC> mode=<MODE>
```

## 常见问题

- Wi-Fi 配网失败：EXE 版查看 `%LOCALAPPDATA%\CodexLight\logs\wifi_setup.out.log` 和 `.err.log`，源码版查看 `Bridge/Source/logs`；同时关闭 PlatformIO Monitor，并确认使用 2.4 GHz Wi-Fi。
- 无线不更新：确认同一局域网、防火墙允许 UDP 4210，并重启托盘重新发现设备。
- 黄灯慢闪：Wi-Fi 已连接，固件正在等待电脑心跳；打开托盘。
- 红色双闪：有保存的 Wi-Fi，但连接失败或正在重连。
- 颜色错误：确认 `NEO_GRB`、DIN 方向、GPIO 连通性和 5 V 供电。

## 安全

- Wi-Fi 凭据保存在 ESP32 NVS，固件不会通过串口打印密码。
- UDP 未加密也未鉴权，只应在可信局域网使用。

## 验证

```powershell
python -B -m py_compile Bridge\Source\codex_light_monitor.py
powershell -ExecutionPolicy Bypass -File Bridge\Source\build_tray_exe.ps1
cd Firmware
pio run
```

## 许可

项目遵循仓库根目录的 [MIT License](../LICENSE)。

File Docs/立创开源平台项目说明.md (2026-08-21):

## 固件链接：
[固件、3D打印外壳、硬件设计资料](https://github.com/ZoeGet/CodexLight)
## 项目简介
本项目是一套基于 ESP32-C3FH4 的 Codex Desktop 状态灯。电脑端 Bridge 读取本机 Codex 会话日志，将当前状态通过 USB 串口或同一局域网内的 UDP 发送给状态灯；板载 ESP32-C3FH4 根据收到的状态控制红、绿、黄三颗独立 WS2812B，分别显示工作、完成和等待状态。

硬件采用一体化主板设计，板上集成 ESP32-C3FH4、2.4 GHz 天线、40 MHz 晶振、Type-C 数据与供电接口、电池充电及 5 V 升压电路、3.3 V 稳压电路，不需要额外安装 ESP32-C3 开发板。完成首次 USB 配网后，设备可以使用电池或独立电源供电，并通过局域网 UDP 接收电脑端状态。

## 项目参数

- 主控采用 ESP32-C3FH4，板载 40 MHz 晶振和 AN9520-245 2.4 GHz 天线；
- 红色 WS2812B 连接 GPIO7，绿色 WS2812B 连接 GPIO6，黄色 WS2812B 连接 GPIO5；
- 三颗 WS2812B 使用独立 DIN，每路串联 330 Ω 电阻，并分别配置 100 nF 电源去耦电容；
- Type-C 接口同时提供 5 V 供电和 ESP32-C3 原生 USB 数据，D+、D- 各串联 22 Ω 电阻；
- Type-C 的 CC1、CC2 分别通过 5.1 kΩ 电阻下拉到 GND，用于声明设备端口；
- USB VBUS 经过 BAT60JFILM 肖特基二极管接入系统 +5 V，降低系统电源向 USB 端反向灌电的风险；
- ETA6093S2F 电源管理芯片负责单节锂电池开关充电和 5 V 同步升压，外围使用 2.2 µH 电感、22 µF 输出电容、10 µF 电池侧电容和两颗状态指示 LED；
- TLV75733PDBVR 将 +5 V 稳压为 +3.3 V，为 ESP32-C3FH4、射频和逻辑电路供电，输入和输出各配置 1 µF 电容；
- 板上设置 RST 和 BOOT 按键，CHIP_EN 使用 10 kΩ 上拉和 100 nF 电容，GPIO9 使用 10 kΩ 上拉；
- 硬件目录提供 BOM、Gerber 制造包和包含顶层/底层元件信息的 CPL 贴片坐标文件，可用于 PCB 制造与 SMT 贴片；
- 固件串口波特率为 115200，UDP 默认端口为 4210，通信心跳超时时间为 6 秒；
- 固件支持 `WIRED`、`WIRELESS`、`AUTO` 三种通信模式，并将通信模式和 Wi-Fi 配置保存到 ESP32 NVS；
- 红灯表示 Codex 正在思考、回复或运行工具，黄灯表示等待审批、权限或用户输入，绿灯表示空闲、任务完成或任务中止。

## 原理解析（硬件说明）
本项目硬件由 ESP32-C3FH4 主控与射频电路、三路 WS2812B 状态显示电路、Type-C USB 电路、电池充电与 5 V 升压电路、3.3 V 稳压电路组成。USB 和电池电源最终汇入 +5 V 电源网络，再由 U2 生成主控使用的 +3.3 V；电脑端状态则通过原生 USB 串口或 Wi-Fi UDP 进入 ESP32-C3FH4。

  

图1--主控、射频、时钟和按键电路：
U1 使用 ESP32-C3FH4。芯片的 LNA_IN 通过 R9、C11、C12 构成的预留匹配网络连接 AN9520-245 天线；射频电源经过 L3 2 nH 电感，并由 C15、C16、C17 去耦。实际打样时应根据 PCB 材料、天线净空和外壳进行射频测试，R9、C11、C12 的最终参数可根据实测阻抗调整。

X1 为 40 MHz 晶振，C5、C6 均为 15 pF。ESP32-C3FH4 的 VDDA、VDD3P3_RTC、VDD3P3_CPU 等电源引脚分别配置 10 nF、100 nF、1 µF 等去耦电容。RST 按键将 CHIP_EN 拉低复位，R13 为 10 kΩ 上拉，C18 为 100 nF；BOOT 按键将 GPIO9 拉低，配合 R14 10 kΩ 上拉用于进入下载模式。

  
图2--状态灯、Type-C、电池管理和稳压电路：
红、绿、黄三颗 WS2812B 均由 +5 V 供电，DIN 分别经过 R6、R7、R8 三个 330 Ω 电阻连接 GPIO7、GPIO6、GPIO5，DOUT 不再级联。C8、C9、C10 均为 100 nF，分别用于抑制灯珠切换时产生的局部电源波动。

Type-C 接口的两组 D+ 和 D- 分别并联后，经 R3、R4 两个 22 Ω 电阻连接 ESP32-C3FH4 的 GPIO19/USB_D+ 和 GPIO18/USB_D-。R1、R2 均为 5.1 kΩ CC 下拉电阻。VBUS 通过 D1 BAT60JFILM 接入 +5 V，R11 与指示 LED 用于显示 +5 V 电源状态。

U3 ETA6093S2F 集成单节锂电池开关充电和 5 V 同步升压功能。`OUT` 输出系统 +5 V，C4 为 22 µF 输出滤波电容；`SW` 通过 L1（2.2 µH）连接 `VBAT`，`BAT` 也接入 `VBAT`；`LED` 引脚经 R5（1 kΩ）连接 LED1、LED2，用于显示充电和升压工作状态。电池侧 C3 为 10 µF，BAT 接口采用 MX1.25 插座，并设置 SW1 电源开关。U2 TLV75733PDBVR 将 +5 V 转换为 +3.3 V，C2 和 C1 均为 1 µF，R12 与指示 LED 用于显示 +3.3 V 电源状态。

## 软件代码
```
cd Firmware
pio run
pio run -t upload --upload-port COM4

Bridge\CodexLightTray.exe
```
普通用户直接双击 `Bridge\CodexLightTray.exe` 即可使用。该 EXE 内置 64 位 Python 运行时和 `pyserial`，无需另行安装依赖，默认以无线模式驻留系统托盘；首次运行会把运行环境、日志和本地配置释放到 `%LOCALAPPDATA%\CodexLight`。Windows 防火墙首次询问时，请允许专用网络访问。

ESP32-C3 固件位于 [Firmware](https://github.com/ZoeGet/CodexLight/tree/main/Firmware)，电脑端状态监听、USB/UDP Bridge 和 Windows 托盘程序位于 [Bridge](https://github.com/ZoeGet/CodexLight/tree/main/Bridge)，详细烧录、配网和使用方法见 [使用说明](https://github.com/ZoeGet/CodexLight/blob/main/USAGE.md)。

固件接收 `GREEN`、`RED`、`YELLOW` 串口命令，或接收 `CODEXLIGHT/1 GREEN`、`CODEXLIGHT/1 RED`、`CODEXLIGHT/1 YELLOW` UDP 数据包。Bridge 只发送状态，不发送 Codex 对话正文、工具输出、API Key 或登录令牌。

## 注意事项

- ESP32-C3FH4 为 QFN 封装，中心焊盘 EP 必须可靠接地并布置足够的接地过孔，建议使用钢网和回流焊完成焊接；
- 天线周围应按照 PCB 天线规范保留净空，天线下方及前方不要铺铜、走线或放置金属器件，外壳中的电池和螺丝也应远离天线区域；
- R9、C11、C12 属于射频匹配网络，未经网络分析仪或射频测试确认时不要随意改变封装和走线；
- 三颗 WS2812B 使用 +5 V 供电，而 ESP32-C3 输出为 3.3 V 逻辑，数据线应尽量短；若实际测试出现误码、闪烁或需要外接长线，建议增加 3.3 V 转 5 V 电平转换器；
- Type-C D+、D- 应按 USB 差分线布线，保持等长、连续参考地并减少过孔；原理图中未画出 USB ESD/TVS 器件，若用于频繁插拔或复杂电磁环境，建议增加 USB 专用静电保护；
- USB VBUS、电池充电和 5 V 升压共用系统 +5 V 网络，焊接完成后应先检查 D1 方向、电源短路和各电源轨电压，再安装 ESP32-C3FH4；
- 新版原理图中的 R5 是 ETA6093S2F 状态 LED 的限流电阻，不再用于设定充电电流；电池必须带保护板，并确认 MX1.25 接口正负极与电池线序一致；
- ETA6093S2F 的 `OUT`、`SW`、`BAT`、`VBAT` 和 GND 属于大电流路径，PCB 上应尽量短而宽，并将 L1、C3、C4 靠近 U3 放置；组装后应分别验证 USB 充电、断开 USB 后的 5 V 升压以及 LED1/LED2 状态；
- 当前 BOM 和 CPL 仍保留旧的 ETA9697E8A 记录，提交生产前必须从新版 EasyEDA 工程重新导出，并核对 U3 的封装、坐标和旋转方向；
- 首次配网和固件烧录需要可传输数据的 Type-C 线，ESP32-C3 仅支持 2.4 GHz Wi-Fi；
- PlatformIO 串口监视器、串口助手和 Bridge 不能同时占用同一个 USB 串口；
- 无线模式下电脑与状态灯需要处于同一局域网，路由器不能开启 AP 隔离，防火墙需要允许 UDP 4210；
- UDP 状态协议未加密、未鉴权，仅建议在可信局域网中使用。

## 组装流程
首先焊接阻容、电源芯片、晶振和 ESP32-C3FH4，再焊接 Type-C、电池接口、开关、天线和三颗 WS2812B。通电前使用万用表检查 +5 V、+3.3 V、VBAT 与 GND 之间是否短路。
  
图1：对照原理图检查器件型号、阻容数值、芯片方向和未连接引脚，确认无错焊、漏焊和连锡
  
图2：完成主控、射频、晶振和 RST/BOOT 电路焊接后，先检查 +3.3 V 电源，再验证下载模式、复位和程序烧录
  
图3：完成 Type-C、状态灯、电池管理和稳压电路后，依次验证 USB 供电、+5 V、+3.3 V、三颗灯珠及电池独立供电

## 实物图
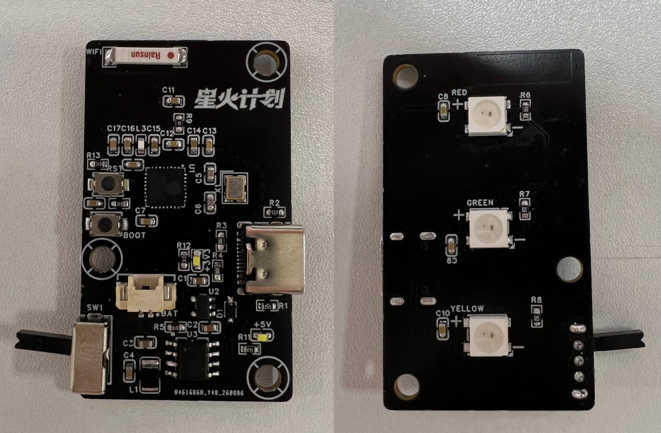
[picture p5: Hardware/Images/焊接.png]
 
图1：CodexLight 一体化主板正反面焊接实物，可见 ESP32-C3FH4 主控与射频区域、Type-C、电池接口与开关、ETA6093S2F 电源区域以及三颗独立 WS2812B 状态灯

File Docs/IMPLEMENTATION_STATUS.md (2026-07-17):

# CodexLight Implementation Status

[Documentation Index](README.md) | [Project Home](../README.en.md) | [中文实现说明](当前实现说明.md)

This document is the technical handoff for the current CodexLight implementation. The root READMEs remain the primary user-facing source of truth.

## Architecture

```text
Codex Desktop logs
        |
        v
Bridge/codex_light_monitor.py
        |
        +-- USB CDC serial: GREEN / RED / YELLOW
        +-- LAN UDP: CODEXLIGHT/1 <STATE>
                         |
                         v
                  ESP32-C3 firmware
                         |
                         +-- GPIO5 yellow WS2812B
                         +-- GPIO6 green WS2812B
                         +-- GPIO7 red WS2812B
```

## Desktop Bridge

Entry point: `Bridge/codex_light_monitor.py`

Primary inputs:

- `~/.codex/sessions/**/*.jsonl`
- `~/.codex/logs_2.sqlite`

State mapping:

| Event | State |
| --- | --- |
| `task_started` | `RED` |
| `agent_message`, `agent_reasoning`, `token_count` | `RED` |
| `function_call`, `function_call_output` | `RED` |
| Tool payload contains approval, permission, or user-input markers | `YELLOW` |
| `task_complete` | `GREEN` |
| `turn_aborted` | `GREEN` |

An active turn does not become green because of `item/completed` or a quiet timeout. `quiet_timeout` is a fallback only when no active turn exists.

When serial opens, the Bridge waits two seconds, sends `MODE WIRED` for serial-only operation or `MODE AUTO` when UDP is also enabled, and sends the current state. Serial and UDP states repeat every two seconds as firmware heartbeats.

UDP begins with broadcast discovery. After receiving a matching `HELLO`, the Bridge records the MAC and IP in the Git-ignored `Bridge/config.local.json` and prefers unicast.

## Firmware

Entry point: `Firmware/src/main.cpp`

Modules:

- `src/config_portal.cpp`: non-blocking WiFiManager provisioning
- `src/led.cpp`: three independent Adafruit NeoPixel outputs
- `include/config.h`: user-facing constants

Each loop iteration:

1. Parses USB serial commands.
2. Calls WiFiManager `process()`.
3. Maintains UDP listening and `HELLO` discovery packets.
4. Selects an active transport from the configured mode and fresh heartbeats.
5. Updates the connection animation or actual LED state.

There is no infinite Wi-Fi wait and no `while (!Serial)`, so standalone and wired operation remain available without a network.

## Transport Modes

- `WIRED`: considers `lastWiredPacketMs` only.
- `WIRELESS`: considers `lastWirelessPacketMs` only.
- `AUTO`: accepts both and prefers a fresh wired heartbeat.

The mode is stored in NVS using Preferences namespace `codexlight`, key `transport`. The source default is `WIRED`. A normal firmware upload does not erase NVS.

## Heartbeat and LED Timing

- Bridge heartbeat interval: 2 seconds
- Firmware link timeout: 6 seconds
- Disconnected blink half-period: 500 ms
- Connection animation duration: 2 seconds
- Connection animation half-period: 250 ms

The LED driver uses `NEO_GRB + NEO_KHZ800`, matching the reference project. Every state transition writes all three independent LED outputs so inactive LEDs are explicitly cleared.

The firmware caches the last rendered LED frame. WS2812B data is sent only when the state or blink phase changes. A `task_complete` green frame therefore remains latched until a later `RED`, `YELLOW`, or disconnected frame replaces it.

## Wi-Fi Provisioning

WiFiManager opens `CodexLight-XXXX` at `192.168.4.1` when no usable credentials exist. The current AP password is `123456789`.

- `WIFI_CONFIG` calls `startConfigPortal()`.
- `CLEAR_WIFI` resets saved settings, disconnects, and reopens the portal.

The ESP32-C3 ultimately operates as a Wi-Fi station on the user's 2.4 GHz LAN. The phone-facing AP is a provisioning mechanism, not the permanent desktop-to-device network.

## Protocol

Serial commands:

```text
GREEN
RED
YELLOW
PING
STATUS
MODE WIRED
MODE WIRELESS
MODE AUTO
WIFI_CONFIG
CLEAR_WIFI
```

UDP states:

```text
CODEXLIGHT/1 GREEN
CODEXLIGHT/1 RED
CODEXLIGHT/1 YELLOW
CODEXLIGHT/1 PING
```

Discovery:

```text
CODEXLIGHT/1 HELLO mac=<MAC> mode=<MODE>
```

## Removed Legacy Behavior

The current implementation no longer uses:

- Hard-coded `wifi_secrets.h` credentials
- A custom blocking configuration page
- UDP token pairing or `PAIR_SET`
- FastLED global multi-controller refresh
- Ordinary `item/completed` logs as a full task-completion signal

## Verification

```powershell
python -B -c "import ast,pathlib; ast.parse(pathlib.Path('Bridge/codex_light_monitor.py').read_text(encoding='utf-8')); print('OK')"

cd Firmware
pio run -j 1
```

The latest NeoPixel firmware build completed successfully. It used approximately 65.5% flash and 12.3% RAM; exact values may change with dependency versions.

## Maintenance Rules

- Keep root and subdirectory documentation synchronized in Chinese and English.
- Do not commit `Bridge/config.local.json`, Wi-Fi credentials, or device-specific IP addresses.
- Preserve non-blocking serial operation when modifying provisioning.
- Treat `task_complete` and `turn_aborted` as the definitive green transitions.
- Rebuild firmware after changing GPIOs, pixel order, or provisioning constants.

## License

The project is distributed under the repository's [MIT License](../LICENSE). Third-party dependencies retain their own licenses.

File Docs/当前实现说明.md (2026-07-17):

# CodexLight 当前实现说明

[返回文档索引](README.md) | [项目主页](../README.md)

本文记录当前代码的架构和关键行为，用于后续维护。用户操作以根目录 `README.md` 为准。

## 总体架构

```text
Codex Desktop logs
        │
        ▼
Bridge/codex_light_monitor.py
        │
        ├─ USB CDC serial: GREEN / RED / YELLOW
        └─ LAN UDP: CODEXLIGHT/1 <STATE>
                         │
                         ▼
                  ESP32-C3 firmware
                         │
                         ├─ GPIO5 yellow WS2812B
                         ├─ GPIO6 green WS2812B
                         └─ GPIO7 red WS2812B
```

## Bridge

入口文件：`Bridge/codex_light_monitor.py`

主要数据源：

- `~/.codex/sessions/**/*.jsonl`
- `~/.codex/logs_2.sqlite`

当前状态规则：

| 事件 | 状态 |
| --- | --- |
| `task_started` | `RED` |
| `agent_message`、`agent_reasoning`、`token_count` | `RED` |
| `function_call`、`function_call_output` | `RED` |
| 调用参数包含批准、权限或用户输入标记 | `YELLOW` |
| `task_complete` | `GREEN` |
| `turn_aborted` | `GREEN` |

活动任务期间不会因 `item/completed` 或静默超时变绿。`quiet_timeout` 只在没有活动 turn 时作为回退。

串口连接后 Bridge 等待 2 秒：仅串口时发送 `MODE WIRED`，串口和 UDP 同时启用时发送 `MODE AUTO`。随后发送当前状态，并每 2 秒重发一次作为固件连接心跳。

UDP 初始广播，收到匹配设备的 `HELLO` 后记录 IP。发现信息写入 `Bridge/config.local.json`，该文件被 Git 忽略。

## 固件

入口文件：`Firmware/src/main.cpp`

主要模块：

- `config_portal.cpp`：WiFiManager 非阻塞 AP 配网
- `led.cpp`：三路独立 Adafruit NeoPixel 驱动
- `config.h`：用户配置

固件主循环持续执行：

1. 解析 USB 串口命令。
2. 调用 WiFiManager `process()`。
3. 管理 Wi-Fi UDP 监听和 `HELLO` 广播。
4. 根据模式和心跳选择活动传输。
5. 更新连接动画或真实 LED 状态。

流程中没有等待 Wi-Fi 的无限阻塞循环，也没有 `while (!Serial)`，因此无网络或未连接电脑时仍能独立运行。

## 通信模式

- `WIRED`：只使用 `lastWiredPacketMs`。
- `WIRELESS`：只使用 `lastWirelessPacketMs`。
- `AUTO`：两者都有效时优先有线。

模式通过 Preferences namespace `codexlight` 的 `transport` 键保存在 NVS。默认模式是 `WIRED`。

## 心跳与 LED

- Bridge 心跳间隔：2 秒。
- 固件连接超时：6 秒。
- 断开闪烁半周期：500 ms，即完整周期 1 秒。
- 建立连接动画：2 秒。
- 连接动画闪烁半周期：250 ms。

LED 驱动与参考项目一致，使用 `NEO_GRB + NEO_KHZ800`。每次状态切换都会分别向三路灯发送数据，关闭非活动灯。

固件缓存最后一次显示的 LED 帧。只有状态或闪烁相位变化时才发送新的 WS2812B 数据；`task_complete` 对应的绿色会持续锁存，直到下一次 `RED`、`YELLOW` 或断开状态覆盖它。

## Wi-Fi 配网

WiFiManager 在无可用凭据时开启 `CodexLight-XXXX` 热点，地址为 `192.168.4.1`。当前密码为 `123456789`。

`WIFI_CONFIG` 调用 `startConfigPortal()`；`CLEAR_WIFI` 调用 `resetSettings()`、清除连接并重新开启 Portal。

ESP32-C3 使用 STA 连接家庭或办公 Wi-Fi。手机 AP 只用于写入目标 Wi-Fi 凭据，不是电脑与设备长期通信的网络。

## 当前协议

串口：

```text
GREEN
RED
YELLOW
PING
STATUS
MODE WIRED
MODE WIRELESS
MODE AUTO
WIFI_CONFIG
CLEAR_WIFI
```

UDP：

```text
CODEXLIGHT/1 GREEN
CODEXLIGHT/1 RED
CODEXLIGHT/1 YELLOW
CODEXLIGHT/1 PING
```

发现：

```text
CODEXLIGHT/1 HELLO mac=<MAC> mode=<MODE>
```

## 已移除的旧实现

以下内容不再属于当前实现：

- `wifi_secrets.h` 硬编码 Wi-Fi 凭据
- 自定义阻塞配网页
- UDP token 配对和 `PAIR_SET`
- FastLED 多通道全局刷新
- 使用普通 `item/completed` 提前判断整轮任务完成

## 验证基线

```powershell
python -B -c "import ast,pathlib; ast.parse(pathlib.Path('Bridge/codex_light_monitor.py').read_text(encoding='utf-8')); print('OK')"

cd Firmware
pio run -j 1
```

最近验证中，NeoPixel 固件构建成功，Flash 使用约 65.5%，RAM 使用约 12.3%。具体数值会随依赖版本变化。

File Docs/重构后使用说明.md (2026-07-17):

# CodexLight 重构后使用说明

## 通信方式

固件支持三种模式：

- `AUTO`：同时监听 USB 串口和 UDP，优先使用最近收到心跳的有线连接。
- `WIRED`：只使用 USB 串口。
- `WIRELESS`：只使用同一局域网内的 UDP。

默认模式在 `Firmware/include/config.h` 的 `DEFAULT_TRANSPORT_MODE` 中设置。

运行时可通过串口切换并保存：

```text
MODE AUTO
MODE WIRED
MODE WIRELESS
STATUS
```

## 手机 AP 配网

没有可用 Wi-Fi 凭据时，ESP32 会开启：

```text
热点：CodexLight-XXXX
密码：123456789
地址：http://192.168.4.1
```

WiFiManager 采用非阻塞模式，AP 配网期间串口仍然可用。

串口命令：

```text
WIFI_CONFIG   # 强制打开配网页
CLEAR_WIFI    # 清除 Wi-Fi 并打开配网页
```

## LED 行为

- 没有收到有效电脑端心跳：GPIO5 黄灯按 1 秒周期闪烁。
- 首次收到有效有线或无线心跳：GPIO6 绿灯闪烁 2 秒。
- 连接动画结束后：显示电脑端发送的 `GREEN`、`RED` 或 `YELLOW` 真实状态。
- 超过 6 秒没有收到当前通信方式的心跳：回到 GPIO5 黄灯闪烁。

## 电脑端 Bridge

有线：

```powershell
python Bridge\codex_light_monitor.py --serial auto --baud 115200
```

无线：

```powershell
python Bridge\codex_light_monitor.py --udp --udp-port 4210
```

同时启用：

```powershell
python Bridge\codex_light_monitor.py --serial auto --baud 115200 --udp --udp-port 4210
```

Bridge 每 2 秒通过已启用的通信方式重发当前状态，作为连接心跳。

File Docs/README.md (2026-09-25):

# CodexLight Documentation

[项目主页](../README.md) | [Project Home](../README.en.md)

本目录保存面向用户和维护者的补充文档。

This directory contains supplemental documentation for users and maintainers.

| Document | Purpose |
| --- | --- |
| [中文使用说明](../USAGE.md) | 根目录中文操作手册 / Root Chinese operating guide |
| [English Usage Guide](../USAGE.en.md) | Root English operating guide / 根目录英文操作手册 |
| [使用与实现说明](使用与实现说明.md) | 中文操作、架构和维护说明 / Chinese usage, architecture, and maintenance guide |
| [Usage and Implementation Guide](USAGE_AND_IMPLEMENTATION.md) | English usage, architecture, and maintenance guide / 英文操作、架构和维护说明 |
| [获取 Codex 运行状态](获取Codex运行状态.md) | Codex 日志来源、状态判定、调试和排障说明 |

根目录 README 和 USAGE 是主要用户入口。修改协议、配网、连接模式、GPIO、启动方式、纯无线供电或排障流程时，请同步更新中英文文档。

The root README and USAGE files are the primary user-facing source of truth. Update both languages whenever protocol, provisioning, transport modes, GPIOs, startup behavior, standalone power, or troubleshooting steps change.

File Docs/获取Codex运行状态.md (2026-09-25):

# 获取 Codex 运行状态

本文说明 CodexLight Bridge 如何获取 Codex Desktop 的运行状态，以及如何在 Windows 上手动检查、调试和扩展这套机制。

> 本文针对本项目当前实现。Bridge 读取本机 Codex 的会话日志来推断状态，不读取消息正文，也不调用 API Key 或登录令牌。

## 1. 状态获取链路

```text
Codex Desktop
    ├─ 会话事件：%USERPROFILE%\.codex\sessions\**\*.jsonl
    └─ 运行日志：%USERPROFILE%\.codex\logs_2.sqlite
             ↓
Bridge\Source\codex_light_monitor.py
             ↓
GREEN / RED / YELLOW
             ↓
USB 串口或 UDP
             ↓
ESP32-C3 状态灯
```

Bridge 默认每 0.5 秒轮询一次最近两天修改过的 JSONL 会话文件，并同时以只读方式检查 `logs_2.sqlite`。新建会话会从文件开头读取；Bridge 启动前已经存在的旧内容默认跳过，避免把历史任务误判为当前任务。

## 2. 状态含义

| Bridge 状态 | 含义 | 典型事件或条件 | 状态灯 |
| --- | --- | --- | --- |
| `GREEN` | 空闲、任务已结束或任务已中止 | `task_complete`、`turn_aborted`、长时间无活动 | 绿灯 |
| `RED` | Codex 正在处理任务 | `task_started`、用户消息、推理、回复、工具调用或工具输出 | 红灯 |
| `YELLOW` | Codex 正在等待批准、权限或用户输入 | 工具调用中出现 `require_escalated`、`sandbox_permissions`、`request_user_input`、`approval` 或 `permission` | 黄灯 |

状态不是直接从某一条日志文本读取，而是由 `MonitorState` 根据事件顺序维护：

- 收到 `task_started`：进入 `RED`，记录当前 `turn_id`。
- 收到工具调用：记录 `call_id`；普通工具调用保持 `RED`。
- 工具调用包含审批或权限标记：进入 `YELLOW`，直到对应的工具输出到达。
- 收到 `function_call_output` 或 `custom_tool_call_output`：移除对应的未完成调用；如果仍有其他审批等待，继续保持 `YELLOW`，否则回到 `RED`。
- 收到 `task_complete` 或 `turn_aborted`：清空未完成调用，锁定为 `GREEN`，直到下一次新任务开始。
- 没有明确结束事件时，默认经过 20 秒无活动后回到 `GREEN`。

## 3. 日志位置

### 3.1 会话 JSONL

默认目录：

```text
%USERPROFILE%\.codex\sessions
```

Bridge 会递归查找其中最近修改的 `*.jsonl` 文件。每行应当是一个 JSON 对象，常见结构类似：

```json
{
  "type": "event_msg",
  "payload": {
    "type": "task_started",
    "turn_id": "..."
  }
}
```

工具调用通常位于 `response_item` 事件中，`payload.type` 可能是：

```text
function_call
function_call_output
custom_tool_call
custom_tool_call_output
```

### 3.2 SQLite 运行日志

默认文件：

```text
%USERPROFILE%\.codex\logs_2.sqlite
```

Bridge 以只读模式连接 `logs` 表，只处理上次检查之后的新记录。当前实现主要利用 `ERROR` 级别记录辅助维持 `RED`，SQLite 不是状态判断的主要来源；主要状态仍来自会话 JSONL 事件。

## 4. 手动查看当前日志

### 查看最近修改的会话文件

```powershell
$root = Join-Path $env:USERPROFILE ".codex\sessions"
Get-ChildItem -LiteralPath $root -Recurse -Filter *.jsonl |
  Sort-Object LastWriteTime -Descending |
  Select-Object -First 10 FullName, LastWriteTime, Length
```

### 查看某个会话文件末尾内容

```powershell
Get-Content -LiteralPath "C:\path\to\session.jsonl" -Tail 20
```

只查看事件类型，避免把完整消息内容输出到终端：

```powershell
Get-Content -LiteralPath "C:\path\to\session.jsonl" -Tail 100 |
  ForEach-Object {
    try {
      $e = $_ | ConvertFrom-Json
      [pscustomobject]@{
        EventType   = $e.type
        PayloadType = $e.payload.type
      }
    } catch {
      # 忽略尚未写完整的 JSON 行
    }
  }
```

### 查看 SQLite 中最新日志

如果本机安装了 `sqlite3`：

```powershell
sqlite3 "$env:USERPROFILE\.codex\logs_2.sqlite" `
  "SELECT id, level, target FROM logs ORDER BY id DESC LIMIT 20;"
```

没有 `sqlite3` 命令时，可以只使用 Bridge 自身，不需要额外安装 SQLite 工具。

## 5. 启动 Bridge 监控

推荐直接启动托盘程序：

```text
Bridge\CodexLightTray.exe
```

从源码启动并使用 USB 串口：

```powershell
python Bridge\Source\codex_light_monitor.py --serial auto --baud 115200
```

只使用局域网 UDP：

```powershell
python Bridge\Source\codex_light_monitor.py --udp --udp-port 4210
```

同时使用 USB 和 UDP：

```powershell
python Bridge\Source\codex_light_monitor.py `
  --serial auto --baud 115200 `
  --udp --udp-port 4210 --firmware-mode AUTO
```

调试旧会话内容时，可以显式从文件开头处理：

```powershell
python Bridge\Source\codex_light_monitor.py --serial auto --from-start
```

常用调试参数：

| 参数 | 默认值 | 作用 |
| --- | --- | --- |
| `--sessions-root` | `%USERPROFILE%\\.codex\\sessions` | 指定会话目录 |
| `--sqlite` | `%USERPROFILE%\\.codex\\logs_2.sqlite` | 指定 SQLite 日志 |
| `--poll` | `0.5` 秒 | 轮询间隔 |
| `--max-age-days` | `2` 天 | 扫描最近修改的会话文件范围 |
| `--quiet-timeout` | `20` 秒 | 无活动后回到 `GREEN` 的等待时间 |
| `--from-start` | 关闭 | 启动时处理已有 JSONL 内容 |
| `--repeat` | 关闭 | 即使状态未变化也重复发送状态 |

## 6. 如何确认状态已经被获取

1. 启动 Bridge，并保持托盘程序或命令行窗口运行。
2. 在 Codex Desktop 中发送一个简单任务。
3. 观察状态灯：任务处理期间应为红色，完成后应为绿色。
4. 触发需要审批、权限或用户输入的操作时，应显示黄色。
5. 查看 Bridge 日志确认是否发现会话文件和设备：

   - EXE 版：`%LOCALAPPDATA%\CodexLight\logs`
   - 源码版：`Bridge\Source\logs`

如果状态灯完全不变化，先检查会话文件是否在任务期间更新，再检查 Bridge 是否使用了正确的 `--sessions-root` 和 `--sqlite` 路径。

## 7. 常见问题

### 一直是绿色

- Codex Desktop 没有产生新的会话事件。
- Bridge 启动时扫描范围不包含实际会话文件；尝试增加 `--max-age-days`。
- 任务在 Bridge 启动前已经完成；默认不会重放旧 JSONL，调试时使用 `--from-start`。
- Bridge 没有权限读取 `%USERPROFILE%\.codex`。

### 一直是红色

- 当前会话没有写入 `task_complete` 或 `turn_aborted`。
- 仍存在未完成工具调用。
- 可以暂时降低 `--quiet-timeout` 验证轮询和空闲回退逻辑，但这只是诊断手段。

### 一直是黄色

- 某个审批工具调用没有收到对应的工具输出。
- 日志中仍有另一个待批准的调用；Bridge 会在所有审批完成前保持黄色。

### 能看到日志但灯不亮

这表示“状态获取”和“状态发送”需要分开排查：

1. 先确认 Bridge 命令行或 `codex_light_monitor.out.log` 中状态原因是否变化。
2. 有线模式检查 COM 口是否被 PlatformIO Monitor 或其他串口程序占用。
3. 无线模式检查设备 IP、UDP 端口 `4210` 和 Windows 防火墙专用网络权限。

## 8. 安全与兼容性注意事项

- JSONL 和 SQLite 可能包含会话元数据、工具参数或错误信息；排障时不要把完整日志上传到公开位置。
- 只读取日志即可得到本项目需要的三态信号，不要修改 Codex 会话文件或 SQLite 数据库。
- Codex 日志事件格式属于本地实现依赖。若事件名称或目录结构发生变化，应先在样例日志上验证，再修改 `Bridge\Source\codex_light_monitor.py` 的解析逻辑。
- 修改状态规则后，应运行语法检查，并用 `task_started`、工具调用、审批等待、`task_complete`、`turn_aborted` 这几类事件逐项验证。

## 9. 相关源码

- [Bridge README](../Bridge/README.md)
- [codex_light_monitor.py](../Bridge/Source/codex_light_monitor.py)
- [CodexLight 使用说明](../USAGE.md)

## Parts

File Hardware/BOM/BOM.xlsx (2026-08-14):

序号 | 原始需求 | 原始需求 | 原始需求 | 原始需求
序号 | 型号 | 封装 | 单套用量 | 位号
1 | 2.2uH | L1008 | 1 | L1
2 | WS2812 | LED-SMD-5050 | 3 | RED,YELLOW,GREEN
3 | 1uF | C0603 | 4 | C1,C2,C14,C15
4 | BAT60JFILM | SOD-323 | 1 | D1
5 | 10nF | C0603 | 1 | C13
6 | SK-12D07VG7 | SW-TH | 1 | SW1
7 | AN9520-245 | SMD,9.5x2.1mm | 1 | WIFI
8 | 100nF | C0603 | 6 | C7,C8,C9,C10,C18,C19
9 | 10uF | C0603 | 2 | C17,C3
10 | TYPE-C 16PIN | TYPE-C-SMD-16PIN | 1 | TYPE-C
11 | 22Ω | R0603 | 2 | R3,R4
12 | 2pF | C0603 | 2 | C11,C12
13 | MX1.25 BAT | SMD,P=1.25mm,卧贴 | 1 | BAT
14 | 10KΩ | R0603 | 4 | R11,R12,R13,R14
15 | 5.1KΩ | R0603 | 2 | R1,R2
16 | LED_0603 | LED_0603 | 4 | +3V3,+5V,LED1,LED2
17 | HX 3x4x2-2P-1.6N TACTILE SWITCH | SMD,4x3mm | 2 | RST,BOOT
18 | 22uF | C0603 | 1 | C4
19 | 1KΩ | R0603 | 1 | R5
20 | 15pF | C0603 | 2 | C5,C6
21 | 40MHz | SMD3225-4P | 1 | X1
22 | 330 | R0603 | 3 | R6,R7,R8
23 | 0.1uF | C0603 | 1 | C16
24 | 2nH | L0603 | 1 | L3
25 | ETA6093S2F | SOT-23-5 | 1 | U3
26 | ESP32-C3FH4 | QFN-32 | 1 | U1
27 | TLV75733PDBVR | SOT-23-5 | 1 | U2
28 | 0Ω | R0603 | 1 | R9
29 | M3螺丝 | M3螺丝 | 0

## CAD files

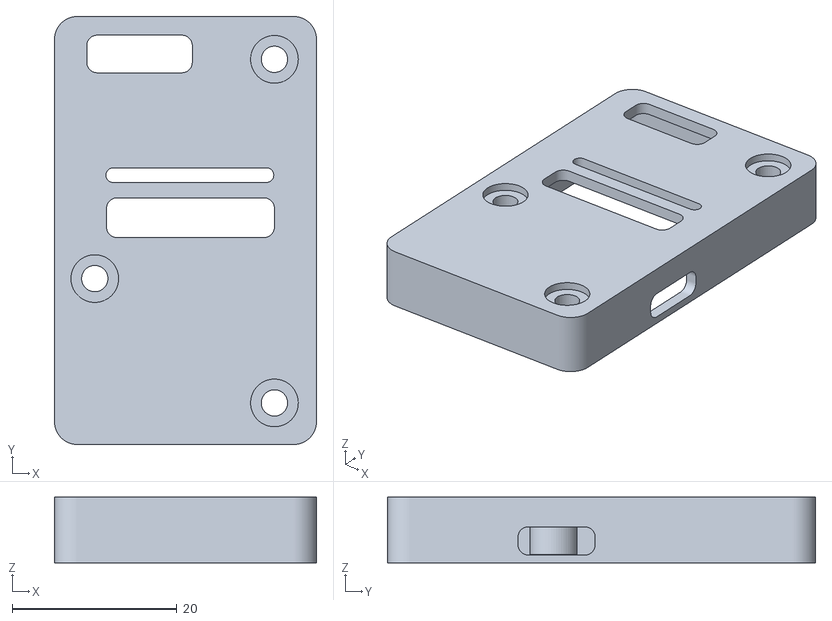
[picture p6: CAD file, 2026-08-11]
Hardware/Enclosure/CodexLight_T.stl
31.9 x 52.0 x 8.00

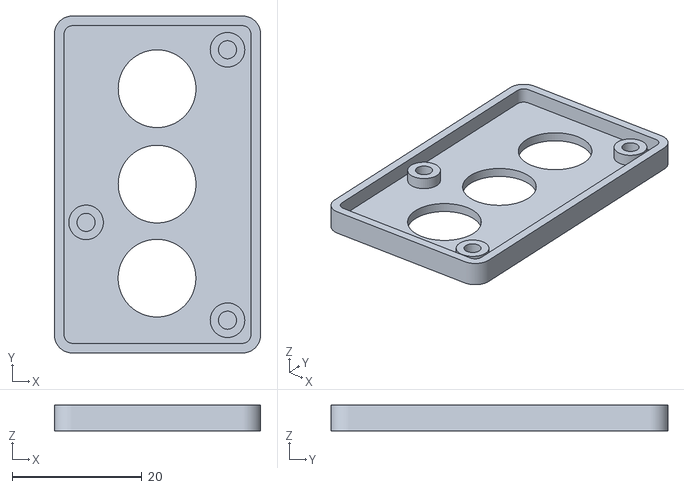
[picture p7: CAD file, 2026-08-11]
Hardware/Enclosure/CodexLight_B.stl
31.9 x 52.0 x 4.00

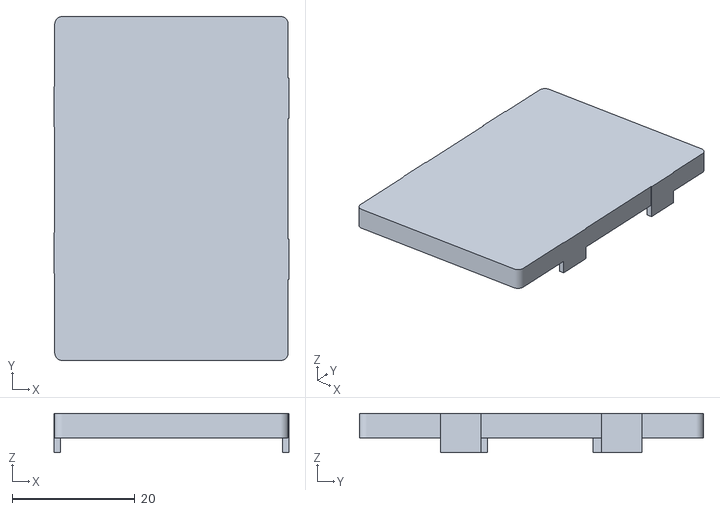
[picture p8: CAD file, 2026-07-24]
Hardware/Enclosure/Battery_T.stl
38.2 x 56.0 x 6.35

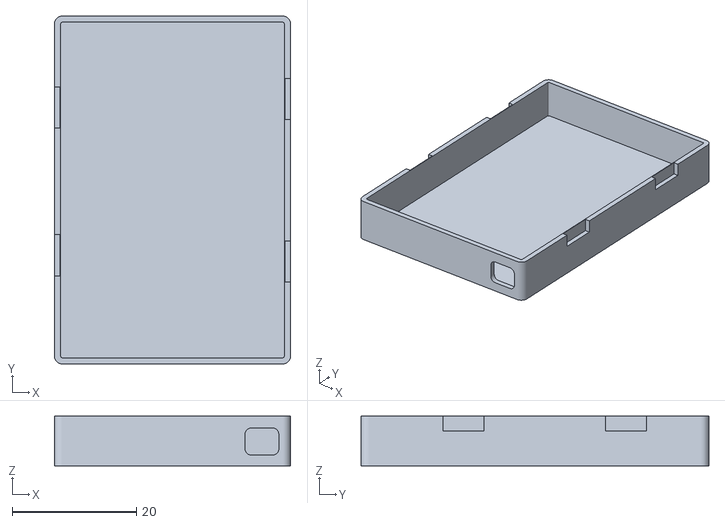
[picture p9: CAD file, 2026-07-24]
Hardware/Enclosure/Battery_B.stl
38.0 x 56.0 x 8.00

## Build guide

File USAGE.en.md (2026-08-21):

# CodexLight Usage Guide

English | [简体中文](USAGE.md) | [Project Home](README.en.md)

This guide covers firmware upload, USB Wi-Fi provisioning, wired/wireless/AUTO modes, Windows tray operation, serial commands, UDP protocol, standalone power, troubleshooting, and verification.

## Prerequisites

Desktop requirements:

- Windows 10/11
- Codex Desktop

`Bridge\CodexLightTray.exe` does not require Python. Python 3.9+ and `pyserial` are needed only when running the Bridge from source.

Firmware development requires PlatformIO Core or the VS Code PlatformIO IDE. PlatformIO installs `Adafruit NeoPixel` automatically.

## Build and Upload

```powershell
cd C:\path\to\CodexLight\Firmware
pio run
pio run -t upload --upload-port COM4
```

Replace `COM4` with the actual ESP32-C3 port. Open the serial monitor with:

```powershell
pio device monitor --port COM4 --baud 115200
```

PlatformIO Monitor, serial terminal apps, and the Bridge cannot use the same COM port at the same time. Close the monitor before starting the tray.

## USB Wi-Fi Provisioning

The current firmware no longer opens an ESP32 AP portal. Use the tray:

1. Connect CodexLight to the computer over USB.
2. Start the tray by double-clicking `Bridge\CodexLightTray.exe`. It defaults to `WIRELESS` mode.
3. Right-click the tray icon and choose `Configure WiFi`.
4. Enter the 2.4 GHz router SSID and password.
5. Click `Save`.

On success, the tray shows `WiFi saved and connected.` The device saves credentials only after a successful connection. Wrong passwords, missing SSIDs, or timeouts do not overwrite the previous saved configuration.

Command-line provisioning is also available:

```powershell
python Bridge\Source\codex_light_monitor.py --serial auto --wifi-ssid "YourWifi" --wifi-password "YourPassword"
```

Successful output:

```text
DEVICE WIFI_SET_OK YourWifi 192.168.x.x
```

EXE failure logs:

```text
%LOCALAPPDATA%\CodexLight\logs\wifi_setup.out.log
%LOCALAPPDATA%\CodexLight\logs\wifi_setup.err.log
```

Source-mode logs remain under `Bridge\Source\logs`.

## Windows Tray

Recommended standalone executable:

```text
Bridge\CodexLightTray.exe
```

The EXE embeds a 64-bit Python runtime and `pyserial`, shows no console window, and defaults to `WIRELESS` mode. On first launch it extracts its runtime, logs, and local configuration to `%LOCALAPPDATA%\CodexLight`. To exit, right-click the tray icon and choose `Exit`.

Windows Firewall may request network access when UDP is first enabled; allow private networks. The source launchers remain available:

```text
Bridge\Source\start_codex_light_tray.vbs
Bridge\Source\start_codex_light_tray.bat
```

Startup mode can be selected explicitly:

```powershell
Bridge\CodexLightTray.exe auto
Bridge\CodexLightTray.exe wired
Bridge\CodexLightTray.exe wireless
Bridge\Source\start_codex_light_tray.bat auto
Bridge\Source\start_codex_light_tray.bat wired
Bridge\Source\start_codex_light_tray.bat wireless
```

Tray menu:

- `Configure WiFi`: configure Wi-Fi over USB.
- `Connection mode`: switch between `Auto`, `Wired only`, and `Wireless only`.
- `Open log folder`: open Bridge logs.
- `Restart monitor`: restart the Bridge monitor process.
- `Exit`: quit the tray app.

## Wired, Wireless, and AUTO Modes

| Mode | Behavior | Recommended use |
| --- | --- | --- |
| `AUTO` | Bridge sends over USB and UDP; firmware prefers a fresh USB heartbeat and can fall back to UDP after USB expires | Daily debugging or mixed connection |
| `WIRED` | USB serial only | Firmware validation, serial debugging, unstable Wi-Fi |
| `WIRELESS` | Wi-Fi UDP only; USB is used only for provisioning or mode setup | Cable-free placement |

The selected mode is stored in ESP32 NVS and survives normal firmware uploads.

## Wireless-Only Workflow

1. Plug into the computer over USB and complete `Configure WiFi` once.
2. From the tray, choose `Connection mode` -> `Wireless only`.
3. Quit the tray.
4. Unplug the computer USB and power the device from a power bank or stable battery-powered 5 V supply.
5. Wait 20 to 60 seconds and check the LED pattern.
6. Start the tray.
7. If the log shows `UDP ack ... active=WIRELESS state=...`, wireless mode is working.

When there is no computer USB connection, these log lines are expected:

```text
SERIAL no matching serial port
SERIAL setup skipped; using saved firmware mode.
```

## LED Behavior and Diagnostics

| LED pattern | Meaning |
| --- | --- |
| Solid green | Idle, task complete, or task aborted |
| Solid red | Codex is reasoning, responding, or running tools |
| Solid yellow | Waiting for approval, permission, or user input |
| Green blink for 2 seconds | First desktop connection established |
| Slow yellow blink | Wi-Fi is connected, but no desktop USB/UDP heartbeat has arrived |
| Alternating red/yellow | No saved Wi-Fi credentials; provision over USB |
| Repeating red double-blink | Saved Wi-Fi exists, but Wi-Fi is reconnecting or failed |

## Manual Bridge Commands

Wired:

```powershell
python Bridge\Source\codex_light_monitor.py --serial auto --baud 115200
```

Wireless:

```powershell
python Bridge\Source\codex_light_monitor.py --udp --udp-port 4210
```

AUTO:

```powershell
python Bridge\Source\codex_light_monitor.py --serial auto --baud 115200 --udp --udp-port 4210 --firmware-mode AUTO
```

Wireless mode requires the computer and ESP32 to be on the same LAN, with router AP/client isolation disabled. Windows Firewall must allow Python to use UDP port `4210`.

## Serial Commands

| Command | Effect |
| --- | --- |
| `GREEN` | Set wired state to green and refresh heartbeat |
| `RED` | Set wired state to red and refresh heartbeat |
| `YELLOW` | Set wired state to yellow and refresh heartbeat |
| `PING` | Refresh wired heartbeat and reply with `PONG` |
| `STATUS` | Print mode, active transport, Wi-Fi, IP, and UDP diagnostics |
| `MODE WIRED` | Use USB only and persist mode |
| `MODE WIRELESS` | Use UDP only and persist mode |
| `MODE AUTO` | Accept USB and UDP and persist mode |
| `WIFI_CONFIG` | Print the USB provisioning hint |
| `WIFI_SET <ssid><TAB><password>` | Configure Wi-Fi over USB; save only after connection succeeds |
| `CLEAR_WIFI` | Clear saved Wi-Fi and wait for provisioning |

## UDP Protocol

Bridge sends:

```text
CODEXLIGHT/1 GREEN
CODEXLIGHT/1 RED
CODEXLIGHT/1 YELLOW
CODEXLIGHT/1 PING
```

ESP32 replies:

```text
CODEXLIGHT/1 ACK mac=<MAC> mode=<MODE> active=<TRANSPORT> state=<STATE>
```

ESP32 also broadcasts discovery:

```text
CODEXLIGHT/1 HELLO mac=<MAC> mode=<MODE>
```

The default UDP port is `4210`.

## Troubleshooting

### Wi-Fi setup fails

- Confirm USB is connected and PlatformIO Monitor or another serial terminal is not using the COM port.
- ESP32-C3 supports 2.4 GHz Wi-Fi only.
- For the EXE build, check `%LOCALAPPDATA%\CodexLight\logs\wifi_setup.out.log` and `.err.log`; source-mode logs are under `Bridge/Source/logs`.
- The current firmware uses the ESP32-C3 SDK default Wi-Fi transmit power, governed by PHY and country configuration.

### Wireless mode does not respond

- Slow yellow blink means Wi-Fi is connected and the device is waiting for tray UDP; start the tray.
- Repeating red double-blink means Wi-Fi is reconnecting or failed; check router, SSID/password, and 2.4 GHz availability.
- If `ping 192.168.x.x` fails and `arp -a` does not show the device MAC, the device is not online on the LAN.
- Restart the tray to force device rediscovery.
- Allow Python through Windows Firewall for UDP `4210`.

### Full factory reset

```powershell
cd Firmware
pio run -t erase --upload-port COM4
pio run -t upload --upload-port COM4
```

## Development Verification

```powershell
python -B -m py_compile Bridge\Source\codex_light_monitor.py
powershell -NoProfile -Command "$e=$null; [System.Management.Automation.PSParser]::Tokenize((Get-Content -LiteralPath 'Bridge\Source\CodexLightTray.ps1' -Raw), [ref]$e) | Out-Null; if($e){$e; exit 1}else{'OK'}"
cd Firmware
pio run
```

For architecture details, see [Docs/USAGE_AND_IMPLEMENTATION.md](Docs/USAGE_AND_IMPLEMENTATION.md).

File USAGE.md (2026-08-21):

# CodexLight 使用说明

[English](USAGE.en.md) | 简体中文 | [返回项目主页](README.md)

本文说明 CodexLight 的固件烧录、USB Wi-Fi 配网、有线/无线/AUTO 模式、Windows 托盘、串口命令、UDP 协议、纯无线供电和排障流程。

## 准备

电脑端需要：

- Windows 10/11
- Codex Desktop

直接使用 `Bridge\CodexLightTray.exe` 不需要安装 Python。只有从源码运行 Bridge 时才需要 Python 3.9+ 和 `pyserial`。

固件端需要 PlatformIO Core 或 VS Code PlatformIO IDE。PlatformIO 会自动安装 `Adafruit NeoPixel`。

## 编译和烧录

```powershell
cd C:\path\to\CodexLight\Firmware
pio run
pio run -t upload --upload-port COM4
```

把 `COM4` 换成实际 ESP32-C3 端口。查看串口输出：

```powershell
pio device monitor --port COM4 --baud 115200
```

PlatformIO Monitor、其他串口程序和 Bridge 不能同时占用同一个 COM 口。使用托盘前先关闭串口监视器。

## USB Wi-Fi 配网

当前固件不再开启 ESP32 热点配网，推荐使用托盘：

1. 用 USB 数据线连接电脑和 CodexLight。
2. 双击 `Bridge\CodexLightTray.exe` 启动托盘。默认是 `WIRELESS` 模式。
3. 右键托盘图标，选择 `Configure WiFi`。
4. 输入 2.4 GHz 路由器 SSID 和密码。
5. 点击 `Save`。

成功后会显示 `WiFi saved and connected.`。设备只会在连接成功后保存 Wi-Fi；密码错误、SSID 不存在或连接超时不会覆盖旧配置。

命令行配网：

```powershell
python Bridge\Source\codex_light_monitor.py --serial auto --wifi-ssid "YourWifi" --wifi-password "YourPassword"
```

成功输出类似：

```text
DEVICE WIFI_SET_OK YourWifi 192.168.x.x
```

EXE 版失败日志：

```text
%LOCALAPPDATA%\CodexLight\logs\wifi_setup.out.log
%LOCALAPPDATA%\CodexLight\logs\wifi_setup.err.log
```

源码版日志仍位于 `Bridge\Source\logs`。

## Windows 托盘

推荐直接双击单文件 EXE：

```text
Bridge\CodexLightTray.exe
```

EXE 内置 64 位 Python 运行时和 `pyserial`，无需额外安装依赖；它不会显示控制台窗口，并默认进入 `WIRELESS` 模式。首次启动会把运行环境、日志和本地配置释放到 `%LOCALAPPDATA%\CodexLight`。退出时请右键托盘图标选择 `Exit`。

首次启用 UDP 时，Windows 防火墙可能询问是否允许网络访问，请允许专用网络。源码启动器仍然保留：

```text
Bridge\Source\start_codex_light_tray.vbs
Bridge\Source\start_codex_light_tray.bat
```

可指定模式：

```powershell
Bridge\CodexLightTray.exe auto
Bridge\CodexLightTray.exe wired
Bridge\CodexLightTray.exe wireless
Bridge\Source\start_codex_light_tray.bat auto
Bridge\Source\start_codex_light_tray.bat wired
Bridge\Source\start_codex_light_tray.bat wireless
```

托盘菜单：

- `Configure WiFi`：通过 USB 配网。
- `Connection mode`：切换 `Auto`、`Wired only`、`Wireless only`。
- `Open log folder`：打开日志目录。
- `Restart monitor`：重启 Bridge 监控进程。
- `Exit`：退出托盘程序。

## 有线、无线和 AUTO 模式

| 模式 | 行为 | 使用建议 |
| --- | --- | --- |
| `AUTO` | Bridge 同时发 USB 和 UDP；固件优先使用 6 秒内新鲜的 USB 心跳，USB 断开后可切到 UDP | 日常调试或混合连接 |
| `WIRED` | 只使用 USB 串口 | 烧录后验证、串口调试、Wi-Fi 不稳定时 |
| `WIRELESS` | 只使用 Wi-Fi UDP；USB 只用于配网或保存模式后释放 | 设备脱离电脑摆放时推荐 |

模式会保存到 ESP32 NVS，普通固件上传不会清除。

## 纯无线使用流程

1. 插电脑 USB，使用 `Configure WiFi` 成功保存 Wi-Fi。
2. 右键托盘，选择 `Connection mode` -> `Wireless only`。
3. 关闭托盘。
4. 断开电脑 USB，使用充电宝或锂电池升压 5 V 供电。
5. 等 20 到 60 秒，观察灯码。
6. 打开托盘。
7. 如果日志出现 `UDP ack ... active=WIRELESS state=...`，纯无线已可用。

无电脑 USB 时，日志中出现下面两行是正常的：

```text
SERIAL no matching serial port
SERIAL setup skipped; using saved firmware mode.
```

## LED 行为和诊断灯码

| 灯光 | 含义 |
| --- | --- |
| 绿灯常亮 | 空闲、任务完成或任务中止 |
| 红灯常亮 | Codex 正在思考、回复或运行工具 |
| 黄灯常亮 | 等待审批、权限或用户输入 |
| 绿灯闪烁 2 秒 | 首次建立电脑连接 |
| 黄灯慢闪 | Wi-Fi 已连接，但未收到电脑 UDP/USB 心跳 |
| 红黄交替 | 没有保存 Wi-Fi 配置，需要 USB 配网 |
| 红色双闪循环 | 有 Wi-Fi 配置，但 Wi-Fi 正在重连或连接失败 |

## 手动运行 Bridge

有线：

```powershell
python Bridge\Source\codex_light_monitor.py --serial auto --baud 115200
```

无线：

```powershell
python Bridge\Source\codex_light_monitor.py --udp --udp-port 4210
```

AUTO：

```powershell
python Bridge\Source\codex_light_monitor.py --serial auto --baud 115200 --udp --udp-port 4210 --firmware-mode AUTO
```

无线模式要求电脑和 ESP32 在同一局域网，路由器没有开启 AP 隔离/客户端隔离，Windows 防火墙允许 Python 使用 UDP 4210。

## 串口命令

| 命令 | 作用 |
| --- | --- |
| `GREEN` | 设置有线状态为绿色并刷新心跳 |
| `RED` | 设置有线状态为红色并刷新心跳 |
| `YELLOW` | 设置有线状态为黄色并刷新心跳 |
| `PING` | 刷新有线心跳，回复 `PONG` |
| `STATUS` | 输出模式、活动传输、Wi-Fi、IP、UDP 诊断 |
| `MODE WIRED` | 只使用 USB，并保存模式 |
| `MODE WIRELESS` | 只使用 UDP，并保存模式 |
| `MODE AUTO` | 接受 USB 和 UDP，并保存模式 |
| `WIFI_CONFIG` | 提示当前使用 USB 配网 |
| `WIFI_SET <ssid><TAB><password>` | 通过 USB 设置 Wi-Fi，连接成功后保存 |
| `CLEAR_WIFI` | 清除已保存 Wi-Fi，等待重新配网 |

## UDP 协议

Bridge 发送：

```text
CODEXLIGHT/1 GREEN
CODEXLIGHT/1 RED
CODEXLIGHT/1 YELLOW
CODEXLIGHT/1 PING
```

ESP32 回复：

```text
CODEXLIGHT/1 ACK mac=<MAC> mode=<MODE> active=<TRANSPORT> state=<STATE>
```

ESP32 也会广播发现包：

```text
CODEXLIGHT/1 HELLO mac=<MAC> mode=<MODE>
```

默认 UDP 端口是 `4210`。

## 排障

### Wi-Fi 配网失败

- 确认 USB 已连接，且 PlatformIO Monitor 或其他串口程序没有占用 COM 口。
- ESP32-C3 只支持 2.4 GHz Wi-Fi。
- EXE 版查看 `%LOCALAPPDATA%\CodexLight\logs\wifi_setup.out.log` 和 `.err.log`；源码版查看 `Bridge/Source/logs`。
- 当前固件使用 ESP32-C3 SDK 默认的 Wi-Fi 发射功率，由 PHY 和地区配置决定。

### 纯无线没有响应

- 黄灯慢闪表示 Wi-Fi 已连接，只是在等托盘 UDP；打开托盘即可。
- 红色双闪表示 Wi-Fi 正在重连或失败，检查路由器、SSID、密码和 2.4 GHz 网络。
- `ping 192.168.x.x` 不通且 `arp -a` 没有设备 MAC 时，设备没有在局域网在线。
- 重启托盘可让 Bridge 重新发现设备 IP。
- Windows 防火墙需要允许 Python UDP 4210。

### 恢复出厂状态

```powershell
cd Firmware
pio run -t erase --upload-port COM4
pio run -t upload --upload-port COM4
```

## 开发验证

```powershell
python -B -m py_compile Bridge\Source\codex_light_monitor.py
powershell -NoProfile -Command "$e=$null; [System.Management.Automation.PSParser]::Tokenize((Get-Content -LiteralPath 'Bridge\Source\CodexLightTray.ps1' -Raw), [ref]$e) | Out-Null; if($e){$e; exit 1}else{'OK'}"
cd Firmware
pio run
```

更多架构说明见 [Docs/使用与实现说明.md](Docs/使用与实现说明.md)。

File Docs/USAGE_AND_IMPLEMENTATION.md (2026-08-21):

# CodexLight Usage and Implementation Guide

English | [简体中文](使用与实现说明.md) | [Documentation Index](README.md) | [Project Home](../README.en.md)

This document combines the operating guide and technical implementation reference for firmware flashing, USB Wi-Fi provisioning, wired/wireless operation, troubleshooting, and maintenance.

## Hardware Connections

| LED | Data pin | State |
| --- | --- | --- |
| Yellow WS2812B | GPIO5 | Disconnected, waiting, or diagnostics |
| Green WS2812B | GPIO6 | Connection animation or task completed |
| Red WS2812B | GPIO7 | Codex is working or Wi-Fi reconnect diagnostics |

Each WS2812B uses an independent DIN. Connect VCC to a stable 5 V supply and share ground with the ESP32-C3.

## Build and Upload

```powershell
cd C:\path\to\CodexLight\Firmware
pio run
pio run -t upload --upload-port COM4
pio device monitor --port COM4 --baud 115200
```

Close PlatformIO Monitor before starting the Bridge because both use the same serial port.

## USB Wi-Fi Provisioning

The current firmware does not open a SoftAP provisioning portal. Provisioning is done over USB serial.

Tray workflow:

1. Connect the device over USB.
2. Double-click `Bridge\CodexLightTray.exe`. It requires no separate Python installation and defaults to `WIRELESS` mode.
3. Right-click the tray icon and choose `Configure WiFi`.
4. Enter SSID/password and save.

Command-line workflow:

```powershell
python Bridge\Source\codex_light_monitor.py --serial auto --wifi-ssid "YourWifi" --wifi-password "YourPassword"
```

Firmware command:

```text
WIFI_SET <ssid><TAB><password>
```

Credentials are saved only after `WiFi.status() == WL_CONNECTED`. Failed attempts are not persisted.

## Transport Modes

| Mode | Behavior |
| --- | --- |
| `WIRED` | USB serial heartbeat only |
| `WIRELESS` | UDP heartbeat only |
| `AUTO` | USB and UDP accepted; USB heartbeat has priority when fresh |

Mode commands:

```text
MODE WIRED
MODE WIRELESS
MODE AUTO
STATUS
```

The mode is stored under Preferences namespace `codexlight`, key `transport`.

## Windows Tray

Normal users double-click the standalone EXE, which defaults to `WIRELESS` mode:

```text
Bridge\CodexLightTray.exe
```

The EXE embeds a 64-bit Python runtime and `pyserial` and extracts them to `%LOCALAPPDATA%\CodexLight` on first launch. Allow private-network access if Windows Firewall prompts. Source debugging can still use `Bridge\Source\start_codex_light_tray.vbs`.

The tray hosts these user actions:

- `Configure WiFi`: USB provisioning.
- `Connection mode`: switches between AUTO, WIRED, and WIRELESS.
- `Open log folder`: opens the active log directory; `%LOCALAPPDATA%\CodexLight\logs` for the EXE and `Bridge/Source/logs` for source mode.
- `Restart monitor`: restarts `codex_light_monitor.py`.
- `Exit`: stops the tray app.

The wireless tray path opens serial only for setup when USB exists, sends a reset pulse and `MODE WIRELESS`, then releases the port. If no USB serial port exists, it logs `SERIAL setup skipped; using saved firmware mode.` and continues over UDP.

## Architecture

```text
Codex Desktop logs
        |
        v
Bridge/Source/codex_light_monitor.py
        |
        +-- USB CDC serial: GREEN / RED / YELLOW / MODE / WIFI_SET
        +-- LAN UDP: CODEXLIGHT/1 <STATE> and CODEXLIGHT/1 PING
                         |
                         v
                  ESP32-C3 firmware
                         |
                         +-- Preferences: wifi ssid/password, transport mode
                         +-- non-blocking saved Wi-Fi reconnect
                         +-- GPIO5 yellow WS2812B
                         +-- GPIO6 green WS2812B
                         +-- GPIO7 red WS2812B
```

## Bridge Implementation

The Bridge reads:

- `~/.codex/sessions/**/*.jsonl`
- `~/.codex/logs_2.sqlite`

It sends only state colors to the device.

| Codex event | Output |
| --- | --- |
| `task_started`, messages, reasoning, tool calls, tool outputs | `RED` |
| Approval, permission, or explicit user input needed | `YELLOW` |
| `task_complete` or `turn_aborted` | `GREEN` |

Session parsing accepts both legacy `function_call` / `function_call_output` and current `custom_tool_call` / `custom_tool_call_output` events. Calls containing `require_escalated`, `sandbox_permissions`, `request_user_input`, or another approval/permission marker remain `YELLOW` until the matching output event resolves the wait.

The tray Wi-Fi setup path pauses the monitor, runs a one-shot `--wifi-config` child process, then restarts the monitor. The EXE writes `wifi_setup.*.log` under `%LOCALAPPDATA%\CodexLight\logs`; source mode writes it under `Bridge/Source/logs`.

## Firmware Implementation

Main files:

- `Firmware/src/main.cpp`: serial command parser, UDP heartbeat, transport selection, LED state machine, diagnostics.
- `Firmware/src/config_portal.cpp`: STA Wi-Fi connection, USB provisioning wrapper, non-blocking saved Wi-Fi reconnect.
- `Firmware/src/storage.cpp`: Preferences storage for Wi-Fi credentials.
- `Firmware/src/led.cpp`: three independent NeoPixel outputs.
- `Firmware/include/config.h`: GPIO, brightness, timeouts, UDP port, default mode, and ESP32-C3 Wi-Fi transmit power.

Wi-Fi notes:

- USB serial is the only provisioning method.
- Credentials are stored only after the STA interface reaches `WL_CONNECTED`.
- Saved Wi-Fi starts non-blockingly at boot, so LED diagnostics and the main loop continue even when the AP is unavailable.
- Failed saved Wi-Fi connections keep credentials and retry every 10 seconds.
- ESP32-C3 uses the SDK default transmit power governed by PHY and country configuration.
- Default debug serial output is disabled for standalone wireless operation.

Startup flow:

```text
setup
  -> initialize LEDs and show startup yellow
  -> read saved Wi-Fi credentials
  -> if present, start STA connection without blocking the main loop
  -> load persisted transport mode
loop
  -> continue saved Wi-Fi reconnect attempts when needed
  -> handle USB serial commands when available
  -> maintain UDP when Wi-Fi is connected
  -> select active transport
  -> render LED state or standalone diagnostics
```

## Protocol

Serial commands:

```text
GREEN
RED
YELLOW
PING
STATUS
MODE WIRED
MODE WIRELESS
MODE AUTO
WIFI_CONFIG
WIFI_SET <ssid><TAB><password>
CLEAR_WIFI
LED_TEST RED
LED_TEST GREEN
LED_TEST YELLOW
LED_TEST OFF
```

UDP states, pings, ACKs, and discovery:

```text
CODEXLIGHT/1 GREEN
CODEXLIGHT/1 RED
CODEXLIGHT/1 YELLOW
CODEXLIGHT/1 PING
CODEXLIGHT/1 ACK mac=<MAC> mode=<MODE> active=<TRANSPORT> state=<STATE>
CODEXLIGHT/1 HELLO mac=<MAC> mode=<MODE>
```

## Troubleshooting

- Wi-Fi setup fails: for the EXE, check `%LOCALAPPDATA%\CodexLight\logs\wifi_setup.out.log` and `.err.log`; for source mode, check `Bridge/Source/logs`. Also close PlatformIO Monitor and verify 2.4 GHz Wi-Fi.
- Wireless does not update: confirm same LAN, allow UDP 4210 through firewall, and restart the tray to rediscover the device.
- Slow yellow blink: Wi-Fi is connected and the firmware is waiting for desktop heartbeats; start the tray.
- Red double-blink: saved Wi-Fi exists but connection is still failing or reconnecting.
- Colors are wrong: verify `NEO_GRB`, DIN orientation, GPIO continuity, and 5 V power.

## Security

- Wi-Fi credentials are stored in ESP32 NVS and are not printed over serial.
- UDP is unauthenticated and unencrypted; use only on trusted LANs.

## Verification

```powershell
python -B -m py_compile Bridge\Source\codex_light_monitor.py
powershell -ExecutionPolicy Bypass -File Bridge\Source\build_tray_exe.ps1
cd Firmware
pio run
```

## License

The project is distributed under the repository [MIT License](../LICENSE).

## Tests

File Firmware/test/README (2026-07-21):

# Firmware Tests

This directory is reserved for PlatformIO unit and hardware-in-the-loop tests.

本目录预留给 PlatformIO 单元测试和硬件在环测试。

There are currently no automated firmware tests. Before submitting firmware changes, run at least:

当前没有自动化固件测试。提交固件修改前至少执行：

```powershell
cd Firmware
pio run
```

Hardware validation should cover:

- USB serial commands: `STATUS`, `MODE ...`, `WIFI_SET`, `CLEAR_WIFI`.
- STA Wi-Fi connection after USB provisioning.
- UDP discovery and heartbeat timeout.
- AUTO/WIRED/WIRELESS mode switching.
- Two-second green connection animation.
- Exclusive red/green/yellow LED output.

硬件验证应覆盖 USB 串口命令、USB 配网后的 STA 联网、UDP 发现和心跳超时、三种模式切换、2 秒绿灯连接动画，以及红/绿/黄三灯互斥显示。

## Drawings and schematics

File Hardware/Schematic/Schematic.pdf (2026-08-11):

# 22uF +5V

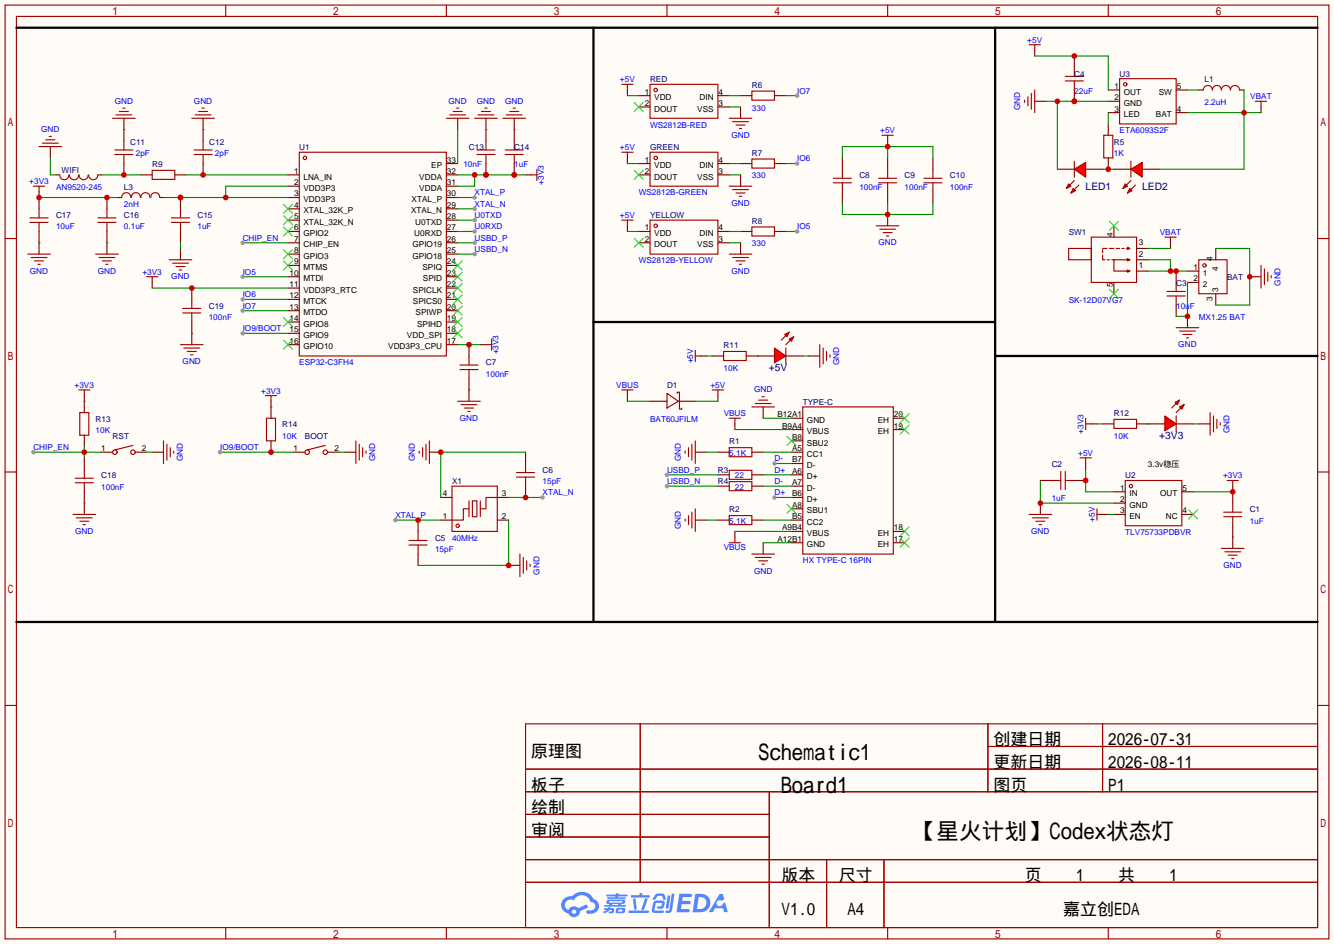
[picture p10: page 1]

原理图 | Schematic1 | 创建日期 | 2026-07-31

更新日期 | 2026-08-11

板子 | Board1 | 图页 | P1
绘制 | | 【星火计划】Codex状态灯
审阅

V1.0 | A4 | 嘉立创EDA

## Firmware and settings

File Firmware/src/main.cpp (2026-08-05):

#include <Arduino.h>
#include <Preferences.h>
#include <WiFi.h>
#include <WiFiUdp.h>

#include "config.h"
#include "config_portal.h"
#include "led.h"

namespace {

using namespace CodexLightConfig;

enum class TransportMode {
  Auto,
  Wired,
  Wireless,
};

enum class Transport {
  None,
  Wired,
  Wireless,
};

enum class LightState {
  Green,
  Red,
  Yellow,
};

enum class LedFrame {
  Off,
  Green,
  Red,
  Yellow,
};

LedController leds;
ConfigPortal configPortal;
Preferences preferences;
WiFiUDP udp;

TransportMode transportMode = TransportMode::Auto;
Transport activeTransport = Transport::None;
LightState wiredState = LightState::Green;
LightState wirelessState = LightState::Green;

String serialBuffer;
bool udpStarted = false;
unsigned long lastWiredPacketMs = 0;
unsigned long lastWirelessPacketMs = 0;
unsigned long lastHelloMs = 0;
unsigned long lastUdpPacketMs = 0;
unsigned long udpPacketCount = 0;
String lastUdpText;
bool linkWasConnected = false;
bool connectionAnimationActive = false;
unsigned long connectionAnimationStartedMs = 0;
LedFrame displayedFrame = LedFrame::Off;
unsigned long lastLedRefreshMs = 0;
void debugPrint(const String& message) {
  if (!DEBUG_SERIAL) {
    return;
  }
  Serial.print("[CodexLight ");
  Serial.print(millis());
  Serial.print(" ms] ");
  Serial.println(message);
}

const char* modeName(TransportMode mode) {
  switch (mode) {
    case TransportMode::Auto:
      return "AUTO";
    case TransportMode::Wired:
      return "WIRED";
    case TransportMode::Wireless:
      return "WIRELESS";
  }
  return "AUTO";
}

const char* transportName(Transport transport) {
  switch (transport) {
    case Transport::Wired:
      return "WIRED";
    case Transport::Wireless:
      return "WIRELESS";
    case Transport::None:
      return "NONE";
  }
  return "NONE";
}

const char* stateName(LightState state) {
  switch (state) {
    case LightState::Green:
      return "GREEN";
    case LightState::Red:
      return "RED";
    case LightState::Yellow:
      return "YELLOW";
  }
  return "GREEN";
}

TransportMode parseMode(String value) {
  value.trim();
  value.toUpperCase();
  if (value == "WIRED") {
    return TransportMode::Wired;
  }
  if (value == "WIRELESS") {
    return TransportMode::Wireless;
  }
  return TransportMode::Auto;
}

bool parseState(String command, LightState& state) {
  command.trim();
  command.toUpperCase();
  if (command.endsWith(" GREEN")) {
    command = "GREEN";
  } else if (command.endsWith(" RED")) {
    command = "RED";
  } else if (command.endsWith(" YELLOW")) {
    command = "YELLOW";
  }

  if (command == "GREEN") {
    state = LightState::Green;
    return true;
  }
  if (command == "RED") {
    state = LightState::Red;
    return true;
  }
  if (command == "YELLOW") {
    state = LightState::Yellow;
    return true;
  }
  return false;
}

void showFrame(LedFrame frame, unsigned long now) {
  const bool frameChanged = frame != displayedFrame;
  const bool refreshDue = now - lastLedRefreshMs >= LED_REFRESH_INTERVAL_MS;
  if (!frameChanged && !refreshDue) {
    return;
  }

  switch (frame) {
    case LedFrame::Off:
      leds.allOff();
      break;
    case LedFrame::Green:
      leds.showGreen();
      break;
    case LedFrame::Red:
      leds.showRed();
      break;
    case LedFrame::Yellow:
      leds.showYellow();
      break;
  }
  displayedFrame = frame;
  lastLedRefreshMs = now;
}

void showState(LightState state, unsigned long now) {
  switch (state) {
    case LightState::Green:
      showFrame(LedFrame::Green, now);
      break;
    case LightState::Red:
      showFrame(LedFrame::Red, now);
      break;
    case LightState::Yellow:
      showFrame(LedFrame::Yellow, now);
      break;
  }
}

bool packetIsFresh(unsigned long packetMs, unsigned long now) {
  return packetMs != 0 && now - packetMs <= LINK_TIMEOUT_MS;
}

Transport selectActiveTransport(unsigned long now) {
  const bool wiredFresh = packetIsFresh(lastWiredPacketMs, now);
  const bool wirelessFresh = packetIsFresh(lastWirelessPacketMs, now);

  if (transportMode == TransportMode::Wired) {
    return wiredFresh ? Transport::Wired : Transport::None;
  }
  if (transportMode == TransportMode::Wireless) {
    return wirelessFresh ? Transport::Wireless : Transport::None;
  }
  if (wiredFresh) {
    return Transport::Wired;
  }
  if (wirelessFresh) {
    return Transport::Wireless;
  }
  return Transport::None;
}

void saveMode() {
  preferences.begin("codexlight", false);
  preferences.putString("transport", modeName(transportMode));
  preferences.end();
}

void saveMode(TransportMode mode) {
  transportMode = mode;
  saveMode();
  lastWiredPacketMs = 0;
  lastWirelessPacketMs = 0;
}

void loadMode() {
  preferences.begin("codexlight", false);
  const String saved = preferences.getString("transport", DEFAULT_TRANSPORT_MODE);
  preferences.end();
  transportMode = parseMode(saved);
}

void printStatus() {
  Serial.print("STATUS mode=");
  Serial.print(modeName(transportMode));
  Serial.print(" active=");
  Serial.print(transportName(activeTransport));
  Serial.print(" wifi=");
  Serial.print(configPortal.wifiConnected() ? "CONNECTED" : "DISCONNECTED");
  Serial.print(" sta_status=");
  Serial.print(configPortal.wifiStatusName());
  Serial.print(" target_ssid=");
  if (configPortal.configuredSsid().length() > 0) {
    Serial.print(configPortal.configuredSsid());
  } else {
    Serial.print("NONE");
  }
  Serial.print(" disconnect_reason=");
  Serial.print(configPortal.lastDisconnectReason());
  Serial.print(" network=");
  Serial.print(configPortal.stateName());
  Serial.print(" radio=");
  switch (WiFi.getMode()) {
    case WIFI_MODE_NULL:
      Serial.print("OFF");
      break;
    case WIFI_MODE_STA:
      Serial.print("STA");
      break;
    case WIFI_MODE_AP:
      Serial.print("AP");
      break;
    case WIFI_MODE_APSTA:
      Serial.print("AP_STA");
      break;
    default:
      Serial.print("UNKNOWN");
      break;
  }
  if (configPortal.wifiConnected()) {
    Serial.print(" ip=");
    Serial.print(WiFi.localIP());
  }
  Serial.print(" udp_packets=");
  Serial.print(udpPacketCount);
  Serial.print(" last_udp_ms=");
  Serial.print(lastUdpPacketMs);
  if (lastUdpText.length() > 0) {
    Serial.print(" last_udp=");
    Serial.print(lastUdpText);
  }
  Serial.println();
}

void handleControlCommand(String command) {
  command.trim();
  String upper = command;
  upper.toUpperCase();

  if (upper.startsWith("MODE ")) {
    saveMode(parseMode(upper.substring(5)));
    Serial.println(String("MODE_OK ") + modeName(transportMode));
    return;
  }
  if (upper == "STATUS") {
    printStatus();
    return;
  }
  if (upper == "WIFI_CONFIG") {
    Serial.println("WIFI_USB_PROVISIONING READY FORMAT=WIFI_SET <ssid><TAB><password>");
    return;
  }
  if (upper == "CLEAR_WIFI") {
    configPortal.resetSettings();
    Serial.println("WIFI_CLEARED USB_PROVISIONING");
    return;
  }
  if (upper.startsWith("WIFI_SET ")) {
    const int separator = command.indexOf('\t', 9);
    if (separator < 0) {
      Serial.println("WIFI_SET_ERROR FORMAT");
      return;
    }
    String ssid = command.substring(9, separator);
    const String password = command.substring(separator + 1);
    ssid.trim();
    if (ssid.length() == 0 || ssid.length() > 32 || password.length() > 64 ||
        (password.length() > 0 && password.length() < 8)) {
      Serial.println("WIFI_SET_ERROR INVALID_CREDENTIALS");
      return;
    }
    configPortal.configure(ssid, password);
    if (configPortal.wifiConnected()) {
      saveMode(TransportMode::Wireless);
      Serial.println(String("WIFI_SET_OK ") + ssid + " " + WiFi.localIP().toString());
    } else {
      Serial.println(String("WIFI_SET_ERROR CONNECT_FAILED ") + ssid);
    }
    return;
  }
  if (upper == "LED_TEST RED") {
    showFrame(LedFrame::Red, millis());
    Serial.println("LED_TEST_OK RED");
    return;
  }
  if (upper == "LED_TEST GREEN") {
    showFrame(LedFrame::Green, millis());
    Serial.println("LED_TEST_OK GREEN");
    return;
  }
  if (upper == "LED_TEST YELLOW") {
    showFrame(LedFrame::Yellow, millis());
    Serial.println("LED_TEST_OK YELLOW");
    return;
  }
  if (upper == "LED_TEST OFF") {
    showFrame(LedFrame::Off, millis());
    Serial.println("LED_TEST_OK OFF");
    return;
  }
  LightState state;
  if (upper == "PING") {
    lastWiredPacketMs = millis();
    Serial.println("PONG");
    return;
  }
  if (parseState(upper, state)) {
    wiredState = state;
    lastWiredPacketMs = millis();
    Serial.println(String("STATE_OK ") + stateName(state));
  }
}

void handleSerialInput() {
  while (Serial.available() > 0) {
    const char ch = static_cast<char>(Serial.read());
    if (ch == '\n' || ch == '\r') {
      if (serialBuffer.length() > 0) {
        handleControlCommand(serialBuffer);
        serialBuffer = "";
      }
      continue;
    }
    if (serialBuffer.length() < 128) {
      serialBuffer += ch;
    } else {
      serialBuffer = "";
    }
  }
}

void sendHello() {
  if (!udpStarted) {
    return;
  }
  const String message = "CODEXLIGHT/1 HELLO mac=" + WiFi.macAddress() +
                         " mode=" + modeName(transportMode);
  udp.beginPacket(IPAddress(255, 255, 255, 255), UDP_PORT);
  udp.print(message);
  udp.endPacket();
}

void sendUdpAck(IPAddress remoteIp, uint16_t remotePort) {
  if (!udpStarted) {
    return;
  }
  const String message = "CODEXLIGHT/1 ACK mac=" + WiFi.macAddress() +
                         " mode=" + modeName(transportMode) +
                         " active=" + transportName(activeTransport) +
                         " state=" + stateName(activeTransport == Transport::Wired ? wiredState : wirelessState);
  udp.beginPacket(remoteIp, remotePort);
  udp.print(message);
  udp.endPacket();
}

void maintainUdp() {
  if (!configPortal.wifiConnected()) {
    if (udpStarted) {
      udp.stop();
      udpStarted = false;
    }
    return;
  }

  if (!udpStarted) {
    udpStarted = udp.begin(UDP_PORT) == 1;
    if (udpStarted) {
      debugPrint("UDP listening on " + String(UDP_PORT) + " at " + WiFi.localIP().toString());
      sendHello();
    }
  }

  if (!udpStarted) {
    return;
  }

  const unsigned long now = millis();
  if (now - lastHelloMs >= 2000UL) {
    lastHelloMs = now;
    sendHello();
  }

  const int packetSize = udp.parsePacket();
  if (packetSize <= 0) {
    return;
  }

  const IPAddress remoteIp = udp.remoteIP();
  const uint16_t remotePort = udp.remotePort();

  char packet[128];
  const int length = udp.read(packet, sizeof(packet) - 1);
  if (length <= 0) {
    return;
  }
  packet[length] = '\0';

  String command(packet);
  lastUdpPacketMs = now;
  udpPacketCount += 1;
  lastUdpText = command;
  lastUdpText.trim();
  LightState state;
  String upper = command;
  upper.trim();
  upper.toUpperCase();
  if (upper == "PING" || upper == "CODEXLIGHT/1 PING") {
    lastWirelessPacketMs = now;
    activeTransport = selectActiveTransport(now);
    sendUdpAck(remoteIp, remotePort);
  } else if (parseState(upper, state)) {
    wirelessState = state;
    lastWirelessPacketMs = now;
    activeTransport = selectActiveTransport(now);
    sendUdpAck(remoteIp, remotePort);
  }
}

void showNoWifiConfig(unsigned long now) {
  const bool redPhase = (now / 1000UL) % 2 == 0;
  showFrame(redPhase ? LedFrame::Red : LedFrame::Yellow, now);
}

void showWifiReconnect(unsigned long now) {
  const unsigned long phase = now % 2000UL;
  if (phase < 200UL || (phase >= 400UL && phase < 600UL)) {
    showFrame(LedFrame::Red, now);
  } else {
    showFrame(LedFrame::Off, now);
  }
}

void showWaitingForComputer(unsigned long now) {
  const bool on = (now / DISCONNECTED_BLINK_HALF_PERIOD_MS) % 2 == 0;
  showFrame(on ? LedFrame::Yellow : LedFrame::Off, now);
}

void updateLeds() {
  const unsigned long now = millis();
  activeTransport = selectActiveTransport(now);
  const bool connected = activeTransport != Transport::None;

  if (connected && !linkWasConnected) {
    connectionAnimationActive = true;
    connectionAnimationStartedMs = now;
    debugPrint(String("Computer link connected via ") + transportName(activeTransport));
  } else if (!connected && linkWasConnected) {
    connectionAnimationActive = false;
    debugPrint("Computer link disconnected");
  }
  linkWasConnected = connected;

  if (!connected) {
    if (configPortal.wifiConnected()) {
      showWaitingForComputer(now);
    } else if (configPortal.configuredSsid().length() > 0) {
      showWifiReconnect(now);
    } else {
      showNoWifiConfig(now);
    }
    return;
  }

  if (connectionAnimationActive) {
    if (now - connectionAnimationStartedMs < CONNECTED_ANIMATION_MS) {
      const bool on = ((now - connectionAnimationStartedMs) /
                       CONNECTED_BLINK_HALF_PERIOD_MS) % 2 == 0;
      if (on) {
        showFrame(LedFrame::Green, now);
      } else {
        showFrame(LedFrame::Off, now);
      }
      return;
    }
    connectionAnimationActive = false;
  }

  showState(activeTransport == Transport::Wired ? wiredState : wirelessState, now);
}

}  // namespace

void setup() {
  Serial.begin(SERIAL_BAUD);
  delay(500);
  Serial.println();
  Serial.println("CODEXLIGHT READY");

  leds.begin();
  showFrame(LedFrame::Yellow, millis());

  configPortal.begin();
  Serial.println("WIFI_PROVISIONING USB_SERIAL");
  configPortal.autoConnect();
  if (configPortal.wifiConnected()) {
    Serial.println(String("WIFI_CONNECTED ") + WiFi.SSID() + " " + WiFi.localIP().toString());
    maintainUdp();
  } else {
    Serial.println("WIFI_USB_PROVISIONING READY FORMAT=WIFI_SET <ssid><TAB><password>");
  }

  loadMode();
  debugPrint(String("Boot mode=") + modeName(transportMode));
  printStatus();
}

void loop() {
  configPortal.loop();
  handleSerialInput();
  maintainUdp();
  updateLeds();
  delay(2);
}

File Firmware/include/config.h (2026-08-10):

#ifndef CODEXLIGHT_CONFIG_H
#define CODEXLIGHT_CONFIG_H

#include <Arduino.h>

namespace CodexLightConfig {

constexpr uint8_t RED_LED_PIN = 7;
constexpr uint8_t GREEN_LED_PIN = 6;
constexpr uint8_t YELLOW_LED_PIN = 5;

constexpr uint8_t LEDS_PER_CHANNEL = 1;
constexpr uint8_t DEFAULT_BRIGHTNESS = 50;

constexpr unsigned long SERIAL_BAUD = 115200;
constexpr uint16_t UDP_PORT = 4210;
constexpr unsigned long LINK_TIMEOUT_MS = 6000;
constexpr unsigned long WIFI_CONNECT_TIMEOUT_MS = 15000;
constexpr unsigned long WIFI_RECONNECT_INTERVAL_MS = 10000;
constexpr unsigned long DISCONNECTED_BLINK_HALF_PERIOD_MS = 500;
constexpr unsigned long CONNECTED_ANIMATION_MS = 2000;
constexpr unsigned long CONNECTED_BLINK_HALF_PERIOD_MS = 250;
constexpr unsigned long LED_REFRESH_INTERVAL_MS = 1000;

// Change this to "WIRED" or "WIRELESS" to choose a fixed startup mode.
// "AUTO" accepts both transports and prefers a recent wired heartbeat.
constexpr const char* DEFAULT_TRANSPORT_MODE = "AUTO";

// Enables firmware diagnostics on the USB serial port. Open the VS Code /
// PlatformIO serial monitor at SERIAL_BAUD to inspect transport, Wi-Fi, UDP,
// configuration portal, and MAC status while debugging hardware setup.
constexpr bool DEBUG_SERIAL = false;

constexpr uint8_t RED_COLOR_R = 255;
constexpr uint8_t RED_COLOR_G = 0;
constexpr uint8_t RED_COLOR_B = 0;

constexpr uint8_t GREEN_COLOR_R = 0;
constexpr uint8_t GREEN_COLOR_G = 255;
constexpr uint8_t GREEN_COLOR_B = 0;

constexpr uint8_t YELLOW_COLOR_R = 255;
constexpr uint8_t YELLOW_COLOR_G = 255;
constexpr uint8_t YELLOW_COLOR_B = 0;

}  // namespace CodexLightConfig

#endif  // CODEXLIGHT_CONFIG_H

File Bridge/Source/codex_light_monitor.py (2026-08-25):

#!/usr/bin/env python3
"""Monitor local Codex logs and emit CodexLight states.

States:
  GREEN  - idle, completed, or no recent agent activity
  RED    - Codex is thinking, writing, or running tools
  YELLOW - Codex is waiting for approval or explicit user input

The script uses only Python's standard library by default. If --serial is used,
pyserial must be installed in the Python environment running this script.
"""

from __future__ import annotations

import argparse
import ipaddress
import json
import os
import re
import socket
import sqlite3
import subprocess
import time
from dataclasses import dataclass, field
from pathlib import Path
from typing import Dict, Iterable, Optional


STATE_GREEN = "GREEN"
STATE_RED = "RED"
STATE_YELLOW = "YELLOW"
DEFAULT_CONFIG_PATH = Path(__file__).with_name("config.local.json")
SERIAL_READY_DELAY_SECONDS = 2.0
SERIAL_MODE_RETRY_SECONDS = 1.0
SERIAL_RESET_DELAY_SECONDS = 0.15
SESSION_DISCOVERY_INTERVAL_SECONDS = 1.0
NETWORK_REFRESH_INTERVAL_SECONDS = 30.0
UDP_DISCOVERY_GRACE_SECONDS = 6.0
UDP_SUBNET_PROBE_INTERVAL_SECONDS = 2.0
UDP_SUBNET_PROBE_BATCH_SIZE = 24
UDP_SUBNET_PROBE_MAX_ADDRESSES = 1024


def is_lan_address(address: ipaddress.IPv4Address) -> bool:
    lan_ranges = (
        ipaddress.IPv4Network("10.0.0.0/8"),
        ipaddress.IPv4Network("172.16.0.0/12"),
        ipaddress.IPv4Network("192.168.0.0/16"),
    )
    return any(address in network for network in lan_ranges)


def parse_windows_ipv4_routes(route_output: str) -> list[tuple[ipaddress.IPv4Network, ipaddress.IPv4Address]]:
    rows: list[tuple[ipaddress.IPv4Address, ipaddress.IPv4Address, str, ipaddress.IPv4Address]] = []
    for line in route_output.splitlines():
        parts = line.split()
        if len(parts) < 5:
            continue
        try:
            destination = ipaddress.IPv4Address(parts[0])
            netmask = ipaddress.IPv4Address(parts[1])
            interface = ipaddress.IPv4Address(parts[3])
        except ipaddress.AddressValueError:
            continue
        rows.append((destination, netmask, parts[2], interface))

    default_interfaces = {
        interface
        for destination, netmask, _gateway, interface in rows
        if destination == ipaddress.IPv4Address("0.0.0.0")
        and netmask == ipaddress.IPv4Address("0.0.0.0")
        and is_lan_address(interface)
    }

    networks: list[tuple[ipaddress.IPv4Network, ipaddress.IPv4Address]] = []
    for destination, netmask, _gateway, interface in rows:
        if not is_lan_address(interface):
            continue
        if default_interfaces and interface not in default_interfaces:
            continue
        if netmask in {
            ipaddress.IPv4Address("0.0.0.0"),
            ipaddress.IPv4Address("255.255.255.255"),
        }:
            continue
        try:
            network = ipaddress.IPv4Network(f"{destination}/{netmask}", strict=False)
        except (ipaddress.AddressValueError, ipaddress.NetmaskValueError):
            continue
        if network.network_address != destination or interface not in network:
            continue
        item = (network, interface)
        if item not in networks:
            networks.append(item)
    return networks


def discover_local_ipv4_networks() -> list[tuple[ipaddress.IPv4Network, ipaddress.IPv4Address]]:
    if os.name == "nt":
        try:
            result = subprocess.run(
                ["route", "print", "-4"],
                capture_output=True,
                text=True,
                errors="replace",
                timeout=3,
                check=False,
                creationflags=subprocess.CREATE_NO_WINDOW,
            )
        except (OSError, subprocess.SubprocessError):
            result = None
        if result is not None and result.stdout:
            networks = parse_windows_ipv4_routes(result.stdout)
            if networks:
                return networks

    # Portable fallback: collect LAN addresses and assume /24 only when the
    # operating system cannot expose its route table through the path above.
    networks = []
    try:
        addresses = socket.gethostbyname_ex(socket.gethostname())[2]
    except OSError:
        addresses = []
    for value in addresses:
        try:
            interface = ipaddress.IPv4Address(value)
        except ipaddress.AddressValueError:
            continue
        if not is_lan_address(interface):
            continue
        item = (ipaddress.IPv4Network(f"{interface}/24", strict=False), interface)
        if item not in networks:
            networks.append(item)
    return networks


@dataclass
class MonitorState:
    state: str = STATE_GREEN
    reason: str = "startup"
    last_activity: float = field(default_factory=time.monotonic)
    pending_calls: Dict[str, str] = field(default_factory=dict)
    pending_approvals: Dict[str, str] = field(default_factory=dict)
    active_turn_id: Optional[str] = None
    completion_latched: bool = False
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

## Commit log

2026-07-14 docs: add initial schematic
2026-07-14 feat: add WS2812B driver
2026-07-14 docs(hardware): add hardware schematic
2026-07-16 docs(hardware): add 3D printable enclosure files
    [CodexLight_B.stl, CodexLight_T.stl]
2026-07-16 docs(hardware): add PCB manufacturing files
2026-07-16 docs(enclosure): update 3D printable case files
    [CodexLight_B.stl, CodexLight_T.stl]
2026-07-17 feat(firmware): replace custom Wi-Fi portal with WiFiManager
    [codex_light_monitor.py, config.h, main.cpp]
2026-07-17 fix: correct Codex state tracking and LED output
    [codex_light_monitor.py, config.h, led.cpp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]
2026-07-17 fix(firmware): latch completed green state
    [main.cpp]
2026-07-21 fix: add wireless udp acknowledgements
    [codex_light_monitor.py, main.cpp]
2026-07-21 chore: add udp and led diagnostics
2026-07-21 chore: add wireless startup led diagnostics
2026-07-21 fix: prevent usb serial blocking standalone boot
    [config.h, main.cpp]
2026-07-24 hardware: update device and battery enclosures
    [BOM.xlsx, Battery_B.stl, Battery_T.stl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]
2026-08-05 refactor(firmware): simplify provisioning and LED initialization
    Remove obsolete AP provisioning paths and portal status fields. Initialize the LED controller directly and simplify brightness handling.
2026-08-05 feat(hardware): add integrated ESP32-C3FH4 schematic
    Replace the legacy development-board schematic with an integrated ESP32-C3FH4 design featuring native USB Type-C, battery charging, 5 V boost power, 3.3 V regulation, RF circuitry, and independent status LEDs.
2026-08-05 docs(readme): document integrated ESP32-C3FH4 hardware
    Update the Chinese and English READMEs with the custom board architecture, native USB, battery management, regulated power rails, and LED connections.
2026-08-05 docs(hardware): align documentation with retained schematic images
    Add the hardware project description and retained schematic previews. Update the Chinese and English READMEs to use the full schematic, MCU detail, and interface and power detail images. Remove refer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
2026-08-05 chore(hardware): update BOM and Gerber files
    Replace the legacy XLSX bill of materials with the updated XLS file, refresh the PCB Gerber fabrication package, and update the hardware documentation link.
    [BOM.xls, BOM.xlsx]
2026-08-05 chore(hardware): add component placement data
    Add the top- and bottom-side CPL file for SMT assembly. Update the hardware documentation, project description, and Chinese and English READMEs with the placement data path and manufacturing notes.
    [CodexLight_PCB_CPL.csv]
2026-08-10 fix(wifi): remove ESP32-C3 transmit power limit
    Remove the 8.5 dBm cap and use the SDK default transmit power. Update the related Chinese and English documentation.
    [config.h]
2026-08-11 fix(bridge): restore approval state detection
    Support custom tool-call events so pending approvals emit YELLOW. Update the related Chinese and English documentation.
    [codex_light_monitor.py]
2026-08-11 docs(hardware): add soldering image
2026-08-11 chore(hardware): update CodexLight enclosure models
    Update the top and bottom STL files for the 3D-printable CodexLight enclosure.
    [CodexLight_B.stl, CodexLight_T.stl]
2026-08-11 feat(hardware): update ETA6093S2F power circuit
    Update the power-management schematic from ETA9697E8A to ETA6093S2F. Regenerate schematic images and update the related Chinese and English documentation.
2026-08-11 docs(hardware): add assembled board photos to documentation
2026-08-14 feat(hardware): refresh PCB production files
    Replace the legacy XLS BOM with the updated XLSX export.
    Refresh the CPL, Gerber, and EasyEDA source files for the ETA6093S2F hardware revision.
    Remove the obsolete BOM and CPL warning from the EasyEDA project description.
    [BOM.xls, BOM.xlsx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]
2026-08-14 fix(bridge): improve tray Wi-Fi reliability
    [codex_light_monitor.py]
2026-08-17 fix(bridge): prevent periodic console window flash
    Run the Windows route-table probe with CREATE_NO_WINDOW so the hidden tray monitor does not flash a console every network refresh interval.
    [codex_light_monitor.py]
2026-08-25 fix(bridge): detect activity in reopened sessions
    Discover recently modified Codex session files regardless of their creation-date directory so reopened threads update the tray state correctly.
    [codex_light_monitor.py]
2026-08-26 docs: update PCB assembly image
